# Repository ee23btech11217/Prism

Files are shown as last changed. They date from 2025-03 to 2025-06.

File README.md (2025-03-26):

# PrisM
Repository for PrisM, a custom FPGA-based handheld gaming console, built from scratch.

## Working with submodules
To work on this project, first clone the repo with submodules

```bash
    git clone --recurse-submodules --remote-submodules https://github.com/Y10-Labs/Prism
```

If you previously cloned this repo, without recurse submodules

```bash
    git fetch
    git pull
    git submodule update --init --recursive
```

If you are working on a submodule (Ex: Prism-SW), 

```bash
    cd Prism-SW
    git checkout main
```

And make changes.

When you are done making changes, 

```bash
    git add .
    git commit -m "Commit Message"
    git push
```

Then 
```bash
    cd ../ # Back to the project root
    git checkout main
    git submodule update 
    git add .
    git commit -m "Changed submodule X"
    git push
```

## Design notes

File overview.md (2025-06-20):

# PRISM: Custom Handheld Gaming Console

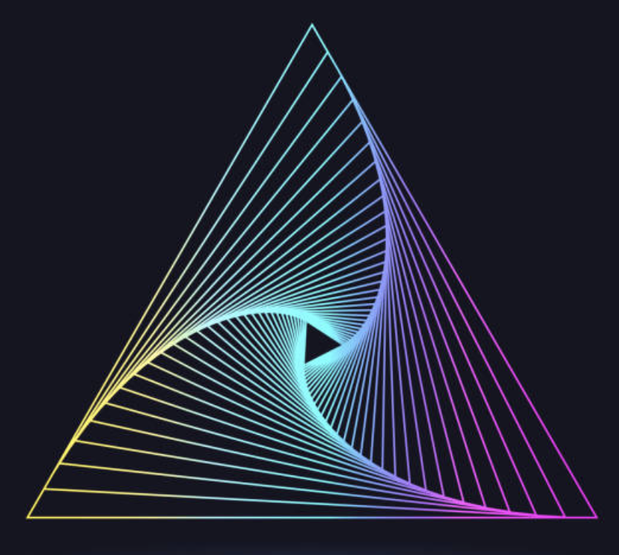
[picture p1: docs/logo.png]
Prism Logo


*A custom-built handheld gaming console with 3D-capable GPU and gyroscopic control*

## Overview

Prism is a handheld gaming console featuring a custom 3D-capable GPU implemented on a Zynq SoC FPGA, complete with fixed-function graphics pipeline and gyroscopic motion control. Designed by Y𝜄𝜋10𝜕 Labs as part of ESDP Lab at IIT Hyderabad.

## Technical Specifications

### Display
- **Resolution**: During development timeline, we plan on testing with the following resolutions
  - Mid-Spec: 400 × 240 @ 60fps
  - Low-Spec: 200 × 120 @ 30fps
- **Screen Size**: 5-inch LCD Panel @ 60Hz
- **Pixel Density**: 151 PPI
- **Color Support**: 15-bit RGB (32,768 colors)

### Controls
- **Gyroscopic Motion**: 6-axis IMU sensor (LSM6DSL)
- **Analog Joystick**: Full 360° with variable pressure
- **D-Pad**: 4-button pad

### Hardware Architecture
- **SoC**: Xilinx Zynq-7000 Series
- **Memory**: 256 MB DDR3 SDRAM
- **Storage**: 2 x SD Card / ROM
- **Graphics**: Custom GPU pipeline implemented in FPGA and ARM core
  - Vertex Shader
  - Shape Assembly
  - Rasterization
  - Pixel Shader
- **Custom Audio Engine**: 
  - Capable of handling upto 255 Channels, each with primitive DSP effects, to interface with the game.
  - Supports basic 2D Spatial Audio

## PCB Design

Mentioning [juliancoy](https://github.com/juliancoy/zynqPCB) as his open-source Zynq PCB design helped us a lot as a starting point.

We heavily modified the design, to incorporate out requirements, and the PCB design looks as follows.

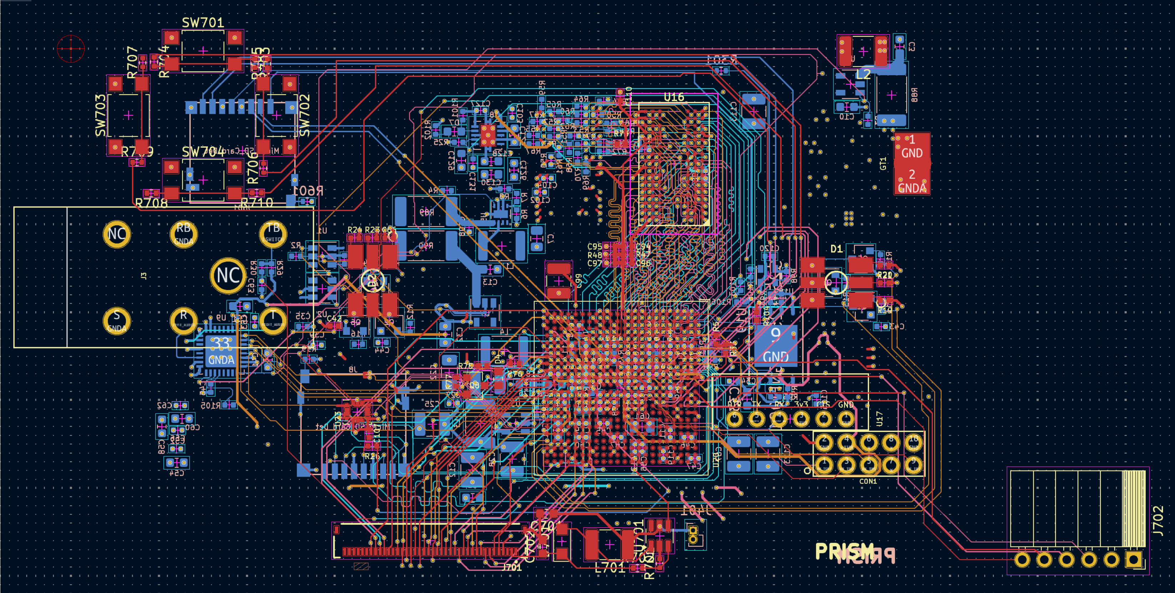
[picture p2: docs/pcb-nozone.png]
pcbnozone

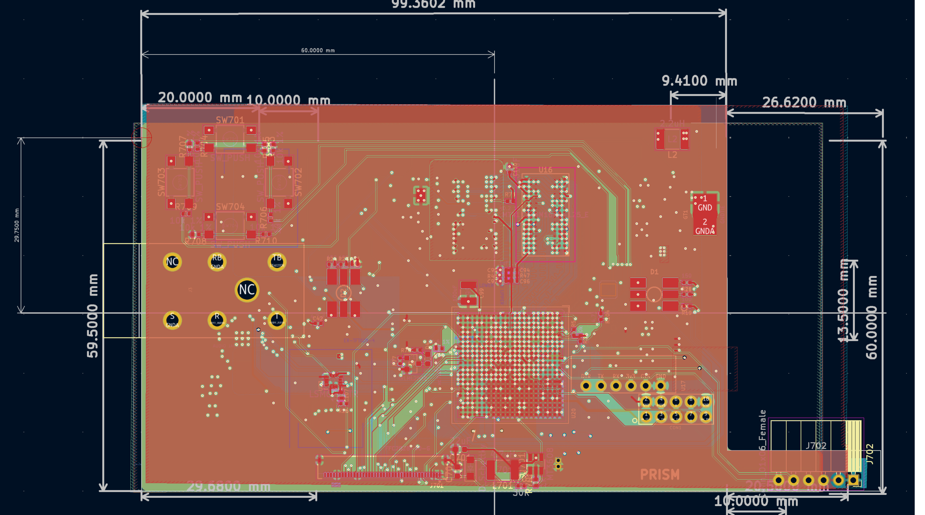
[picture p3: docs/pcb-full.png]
pcbzone

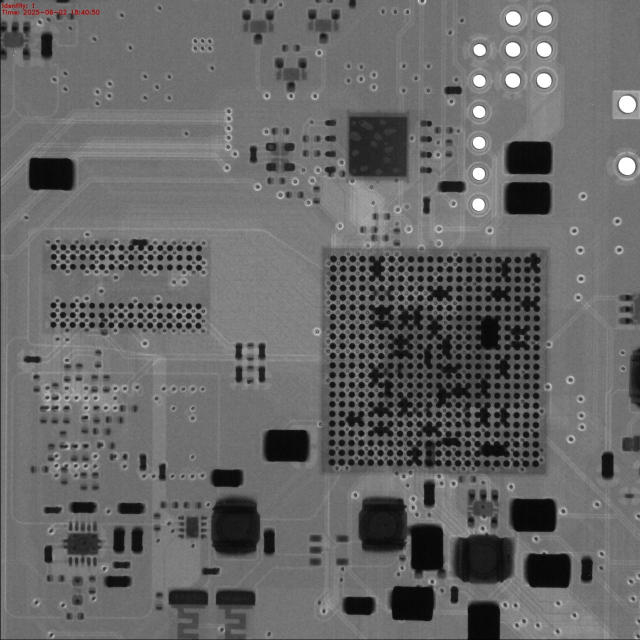
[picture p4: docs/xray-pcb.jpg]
pcbxray

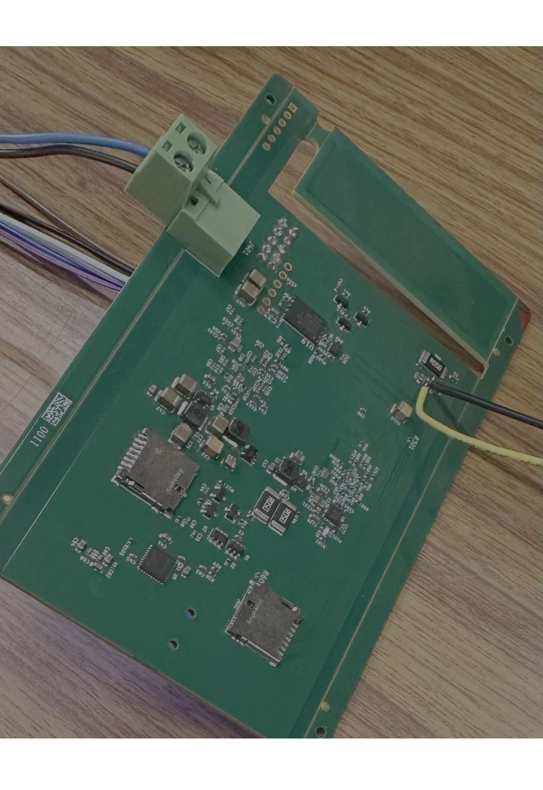
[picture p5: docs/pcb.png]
pcb


## Enclosure

We 3D printed the outer case for the console. The design has space to draw cables out to remaining parts. (It was spray-painted red)
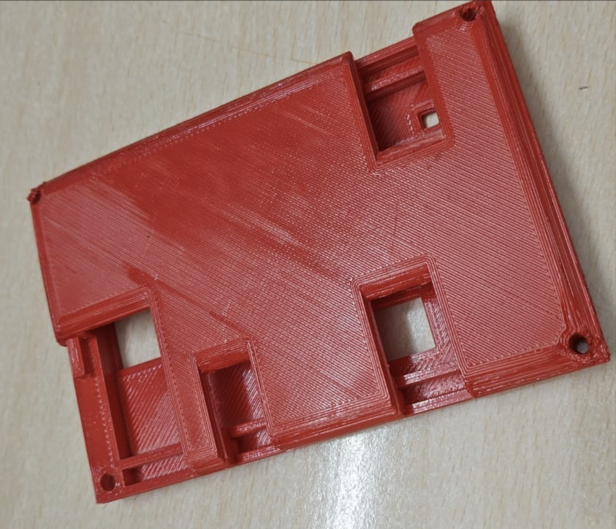
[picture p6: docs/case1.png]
case1

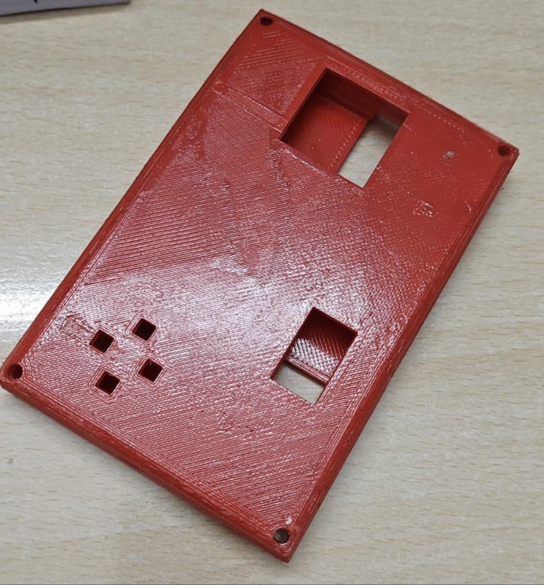
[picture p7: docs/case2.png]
case2


## Software Architecture

### Programming Interface
- C++ for game development (Runs on Petalinux OS)

### Libraries
- **Driver Layer**: Hardware abstraction for:
  - Display output
  - Control inputs
  - Sensors
- **Graphics Layer**:
  - 3D model loading (Loads OBJ only for now)
  - Scene graph management
  - Camera controls

### Game Development Tools
  - Optional OpenGL linking to test game on computer. 

## Project Structure

- **Hardware Design**: PCB and schematic files for Zynq FPGA-based board
- **FPGA Development**: Verilog sources for processor core and GPU
- **Drivers**: C++ access layers for hardware components
- **Graphics Library**: GL-compatible rendering system
- **Emulation**: OpenGL-based desktop emulator

**Software is still under progress**

## Development Timeline

The project is supposed to follow the following timeline:
1. **Phase 1**: Architecture design and specifications freeze
2. **Phase 2**: Low-spec implementation (200 × 120 @ 60fps)
3. **Phase 3**: Mid-spec implementation (400 × 240 @ 60fps)
4. **Phase 4**: PCB design/fabrication and hardware assembly
5. **Phase 5**: Game development and testing

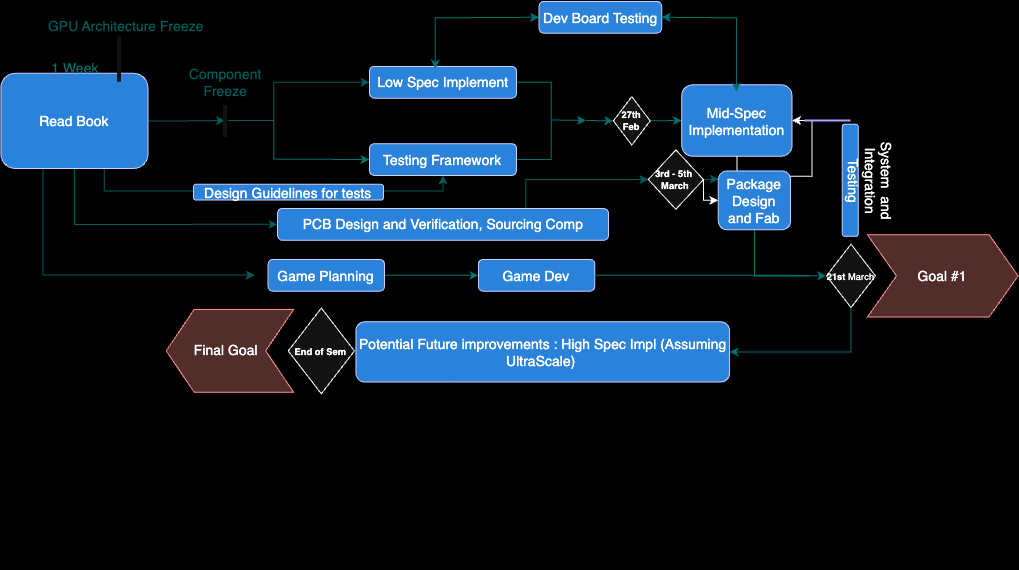
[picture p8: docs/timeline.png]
tiemline


Of course, as with any project, the timeline was only a mere suggestion for what was to happen. We technically hit goals for finishing the PCB, and then waited after that to do everything else.

## Team

Y𝜄𝜋10𝜕 Labs:
- Adarsh A (EE23BTECH11203)
- Manohar K (EE23BTECH11208)
- Prajwal M (EE23BTECH11217)
- Mihir Divyansh Eachempati (EE23BTECH11017)
- Soham Prabhakar More (EE23BTECH11223)
- Sri Krishna Prabhas Yadla (EE23BTECH11224)

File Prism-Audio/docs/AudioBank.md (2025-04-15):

# The PrismAudioBank Format

## Overview

The PrismAudio Bank (.pab) format is a binary container designed to store multiple audio files (wave) for real-time playback on embedded systems. It uses a hierarchical categorization system (Category → Subcategory → Index) to organize sounds

## File Structure

A PrismAudio Bank file consists of three main sections:

1. **Main Header** (20 bytes) - Contains file metadata
2. **Entry Headers** (22 bytes each) - Contains metadata for each audio file
3. **Audio Data** - Contains the raw audio sample data

### Main Header (20 bytes)

| Offset | Size | Type | Description |
|---|---|---|---|
| 0 | 9 | char[9]  | Magic identifier ("PRSMAUBNK") |
| 9 | 1 | uint8_t  | Format version |
| 10 | 4 | uint32_t | Number of entries |
| 14 | 4 | uint32_t | Total header size (22 + 20×entries) |
| 18 | 4 | uint32_t | Total file size |

### Entry Header (22 bytes)

Each entry header contains metadata for one audio sample:

| Offset | Size | Type | Description |
|---|---|---|---|
| 0 | 1 | uint8_t  | Category ID |
| 1 | 1 | uint8_t  | Subcategory ID |
| 2 | 2 | uint16_t | Sound index |
| 4 | 4 | uint32_t | Offset to audio data from start of file |
| 8 | 4 | uint32_t | Length of audio data in bytes |
| 12 | 4 | uint32_t | Number of frames (samples) |
| 16 | 4 | uint32_t | Sample rate in Hz |

### Audio Data Blocks

The audio data section contains raw audio data for each entry:

- Each block contains raw PCM audio data (16-bit samples)
- Blocks are 4-byte aligned
- Block sizes match the lengths specified in the corresponding entry headers
- Blocks appear in the same order as their entry headers

## Sound Identification

Sounds are identified by a three-part hierarchical ID:

- **Category** (uint8_t): Primary classification (e.g., 1=Ambient, 2=Character)
- **Subcategory** (uint8_t): Secondary classification (e.g., 1=Background, 2=Weather)
- **Index** (uint16_t): Specific sound within the subcategory

These three values can be combined to form a unique identifier for each sound in the bank.
```verilog
    32'b{{cat},{subcat},{idx}}
```

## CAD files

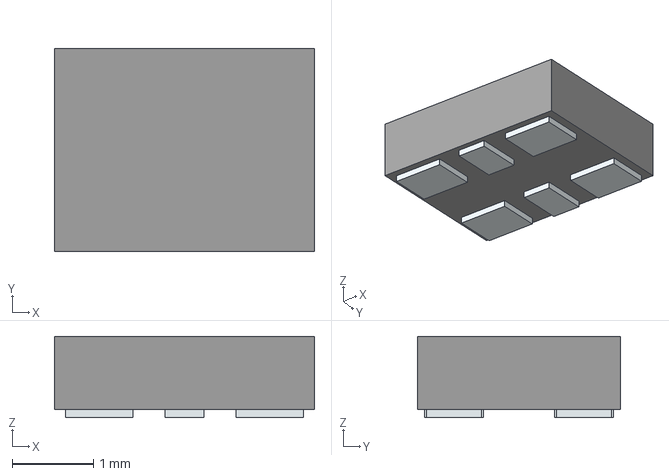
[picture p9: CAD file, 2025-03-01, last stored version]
PCB/custom/LIB_DSC1121CE5-050.0000/DSC1121CE5-050.0000/3D/DSC1121CE5-050.0000.stp
3.20 x 2.50 x 1.00 mm
Pins

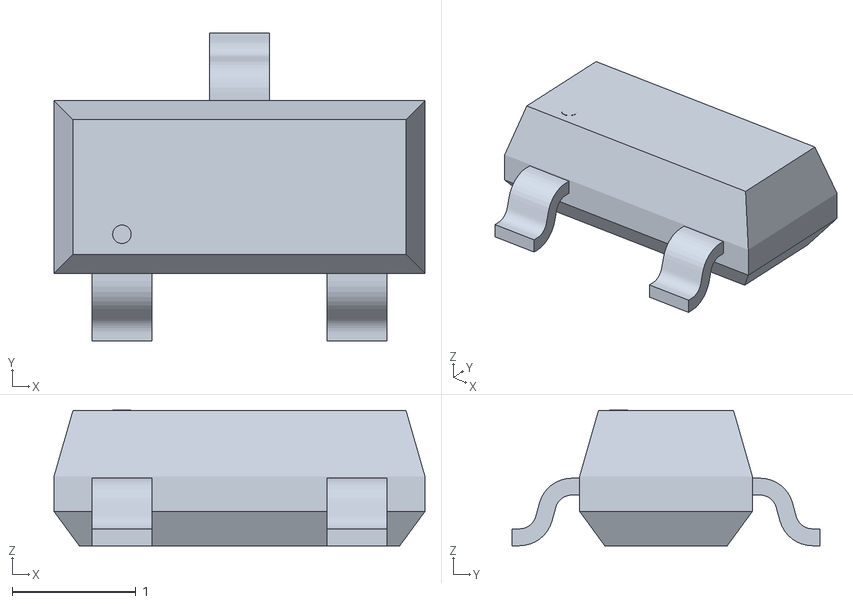
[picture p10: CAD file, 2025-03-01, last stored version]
PCB/custom/PMBT3904_215/SOT23_TO-236AB_NEX.stl
3.00 x 2.49 x 1.10

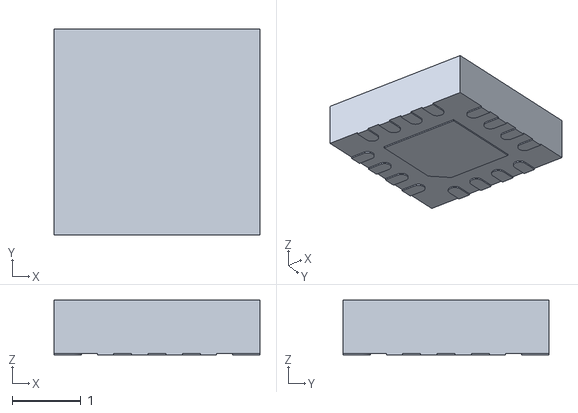
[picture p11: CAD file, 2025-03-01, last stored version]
PCB/custom/TPA6132A2RTET/RTE0016B.stl
3.00 x 3.00 x 0.8

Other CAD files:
PCB/custom/LIB_DSC1121CE5-050.0000/DSC1121CE5-050.0000/Allegro/dsc1121ce50500000.psm
PCB/custom/LIB_DSC1121CE5-050.0000/DSC1121CE5-050.0000/DEHDL/dsc1121ce5_050.0000/chips/chips.prt

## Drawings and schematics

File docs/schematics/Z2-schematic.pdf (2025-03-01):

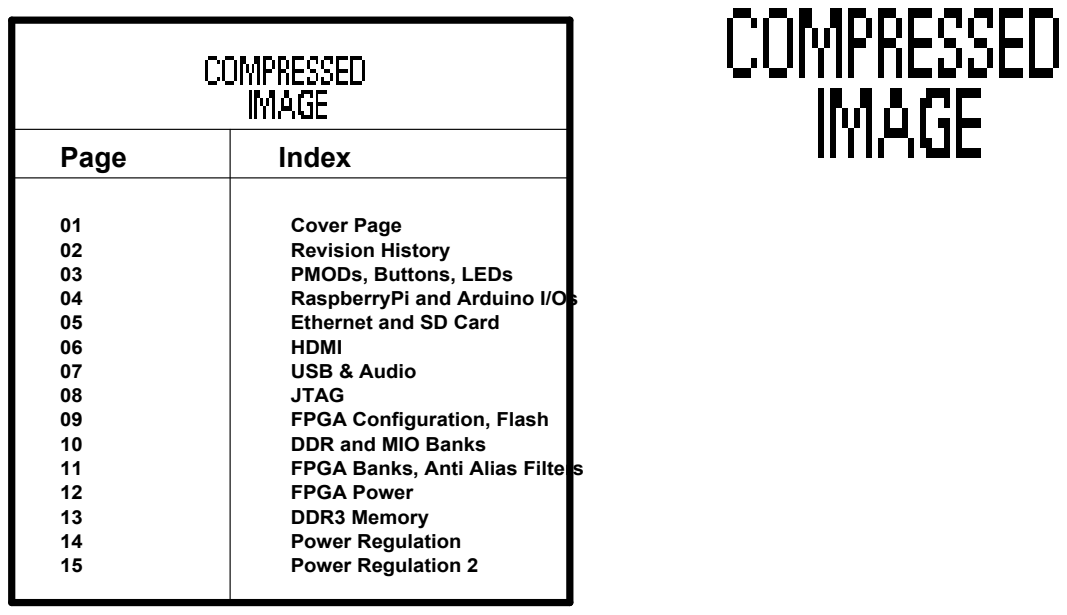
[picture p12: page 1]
Tul Corporation; TEL: +886 2 8698 3000; FAX: +886 2 8698 3456; Cover Page

Page | Index

01 02 Revision History 03 04 05 06 07 08 09 10 11 FPGA Banks, Anti Alias Filters 12 FPGA Power 13 DDR3 Memory 14 Power Regulation 15 Power Regulation 2 | Cover Page PMODs, Buttons, LEDs RaspberryPi and Arduino I/Os Ethernet and SD Card HDMI USB & Audio JTAG FPGA Configuration, Flash DDR and MIO Banks

7F-7,NO.79, HSIN TAI WU RD. SEC 1,
HSI-CHIH, TAIPEI HSIEN, TAIWAN 221
Title

Size A3 | Document Number PYNQ-Z2 | Rev R10

Date: Tuesday, January 09, 2018 Tuesday, January 09, 2018 Tuesday, January 09, 2018 | Sheet 1 1 1 of 15 15 15

# REV

# REVISION HISTORY:

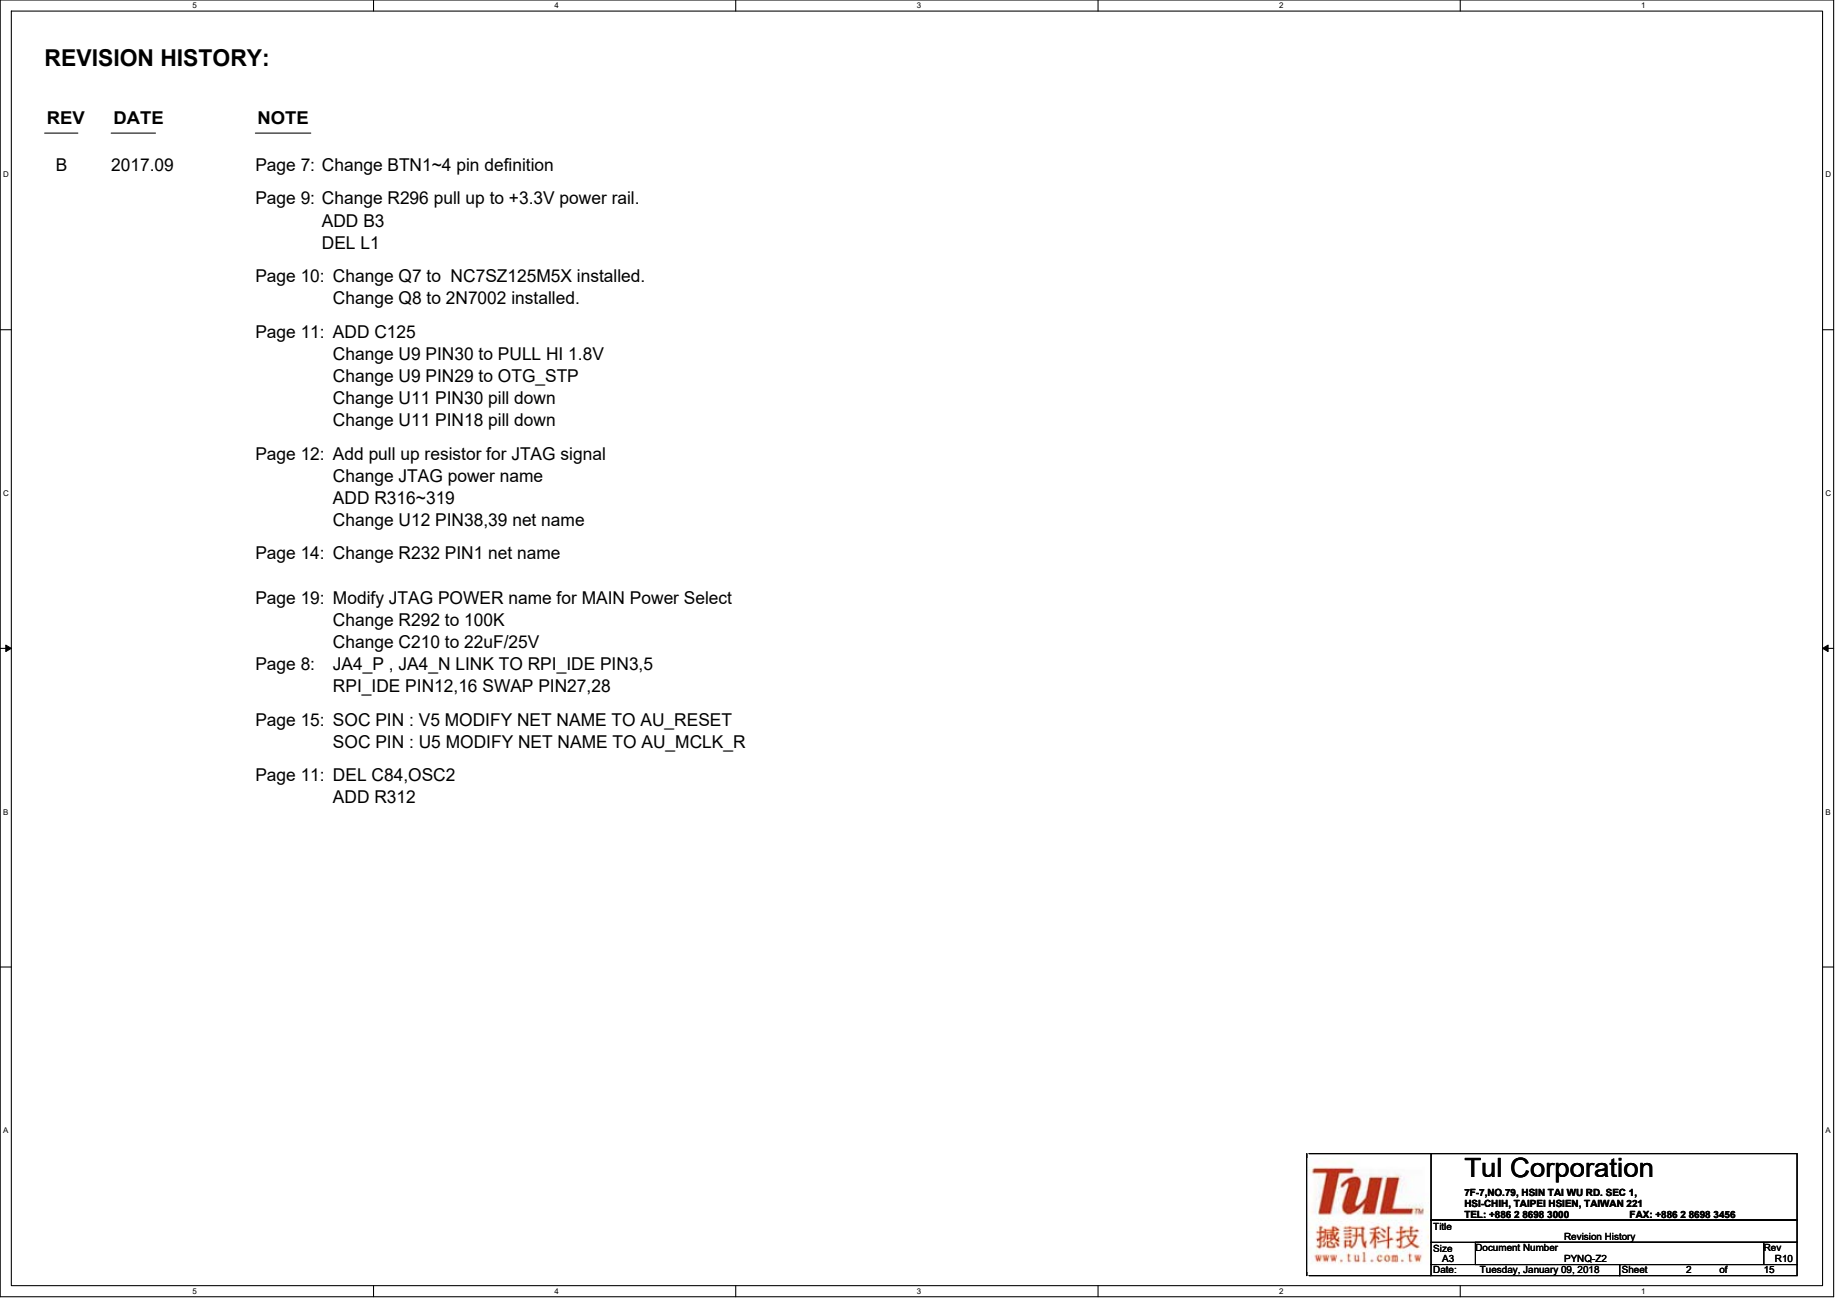
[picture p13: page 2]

Page 9: Change R296 pull up to +3.3V power rail.

Page 10: Change Q7 to NC7SZ125M5X installed.

Change U9 PIN30 to PULL HI 1.8V
Change U9 PIN29 to OTG_STP
Change U11 PIN30 pill down
Change U11 PIN18 pill down

Page 12: Add pull up resistor for JTAG signal

Change JTAG power name
ADD R316~319
Change U12 PIN38,39 net name

Page 14: Change R232 PIN1 net name

Page 19: Modify JTAG POWER name for MAIN Power Select

Page 15: SOC PIN : V5 MODIFY NET NAME TO AU_RESET

SOC PIN : U5 MODIFY NET NAME TO AU_MCLK_R

7F-7,NO.79, HSIN TAI WU RD. SEC 1,

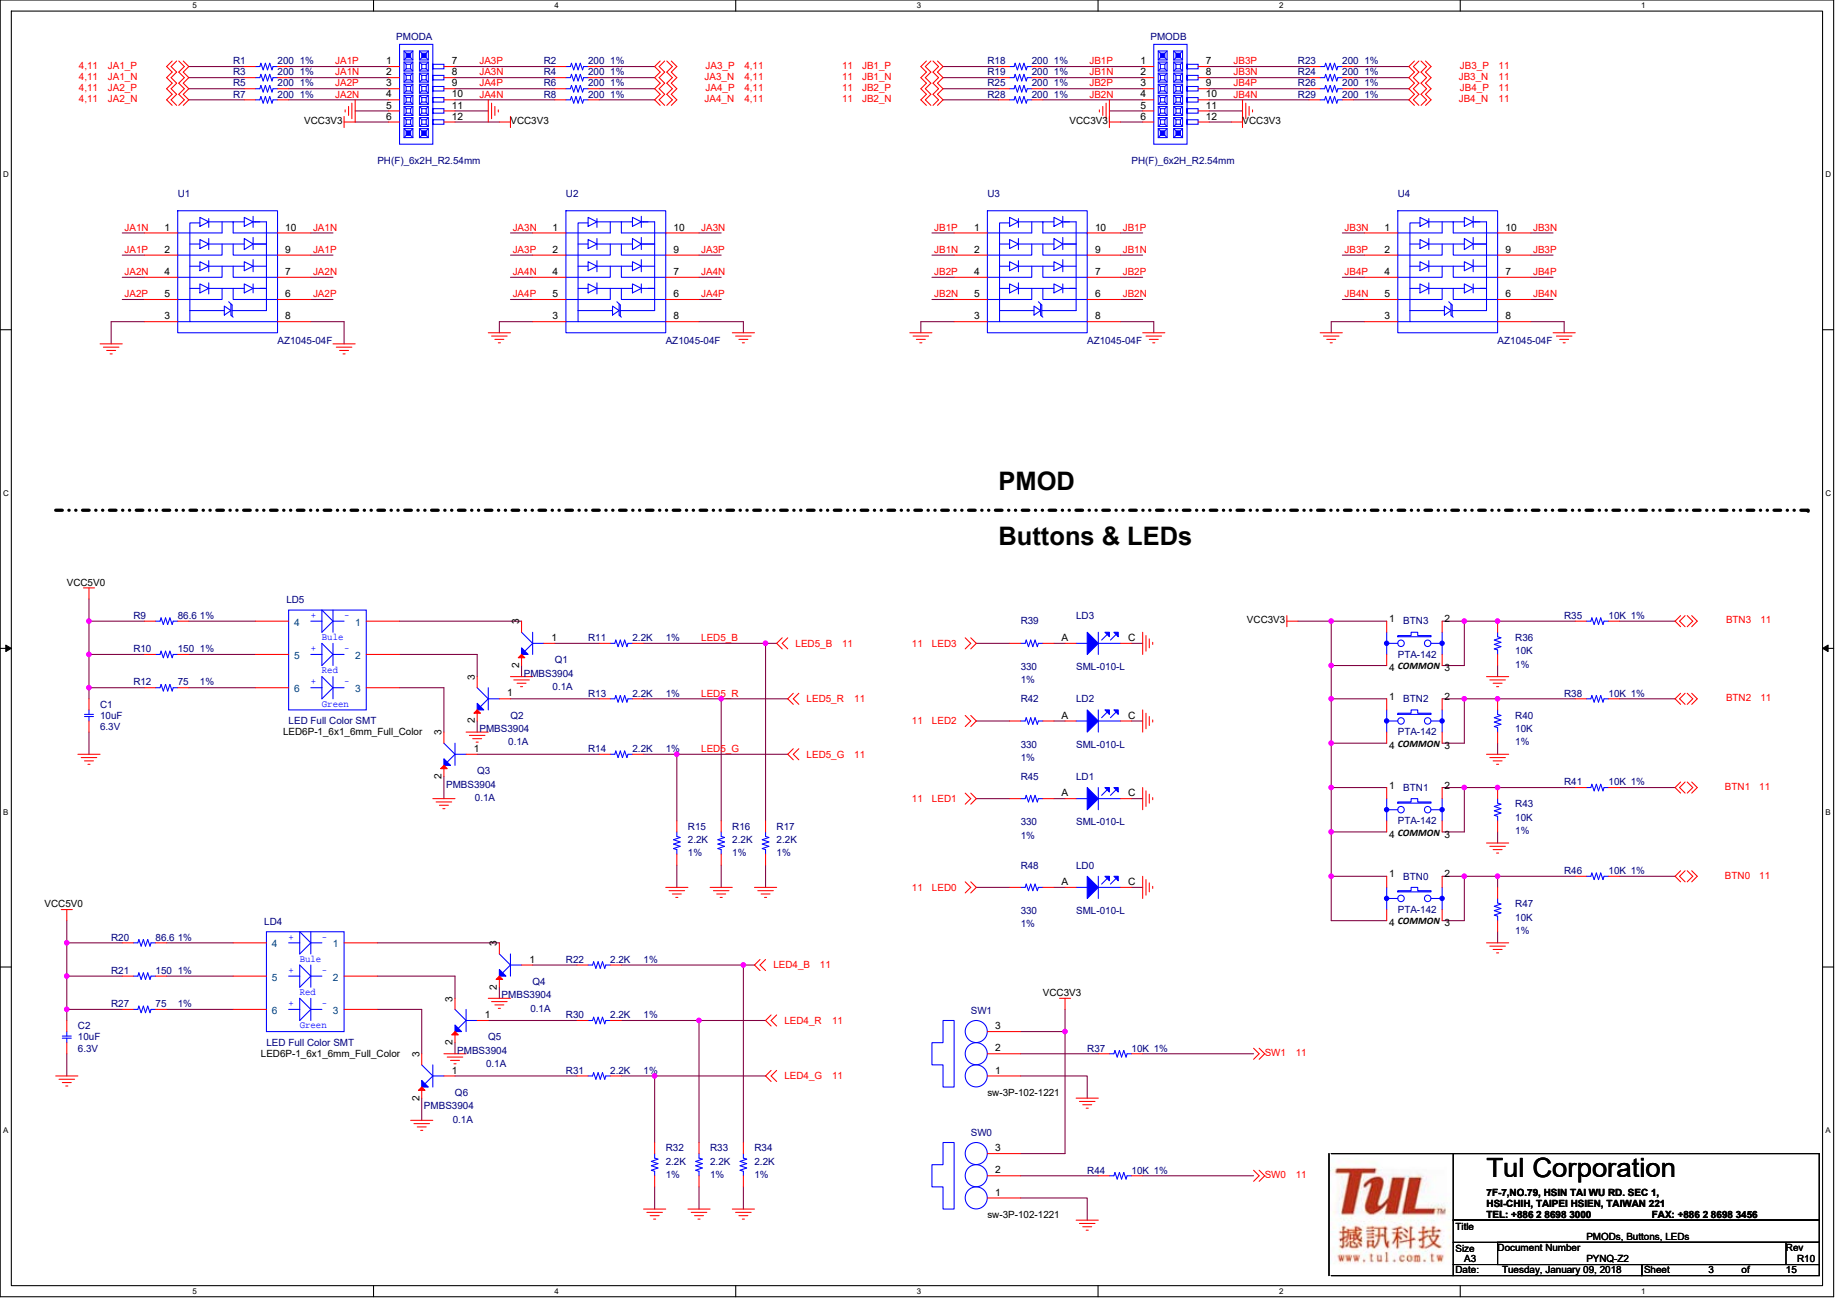
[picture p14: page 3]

LED Full Color SMT
LED6P-1_6x1_6mm_Full_Color

7F-7,NO.79, HSIN TAI WU RD. SEC 1,

Arduino I/Os | Raspberry Pi

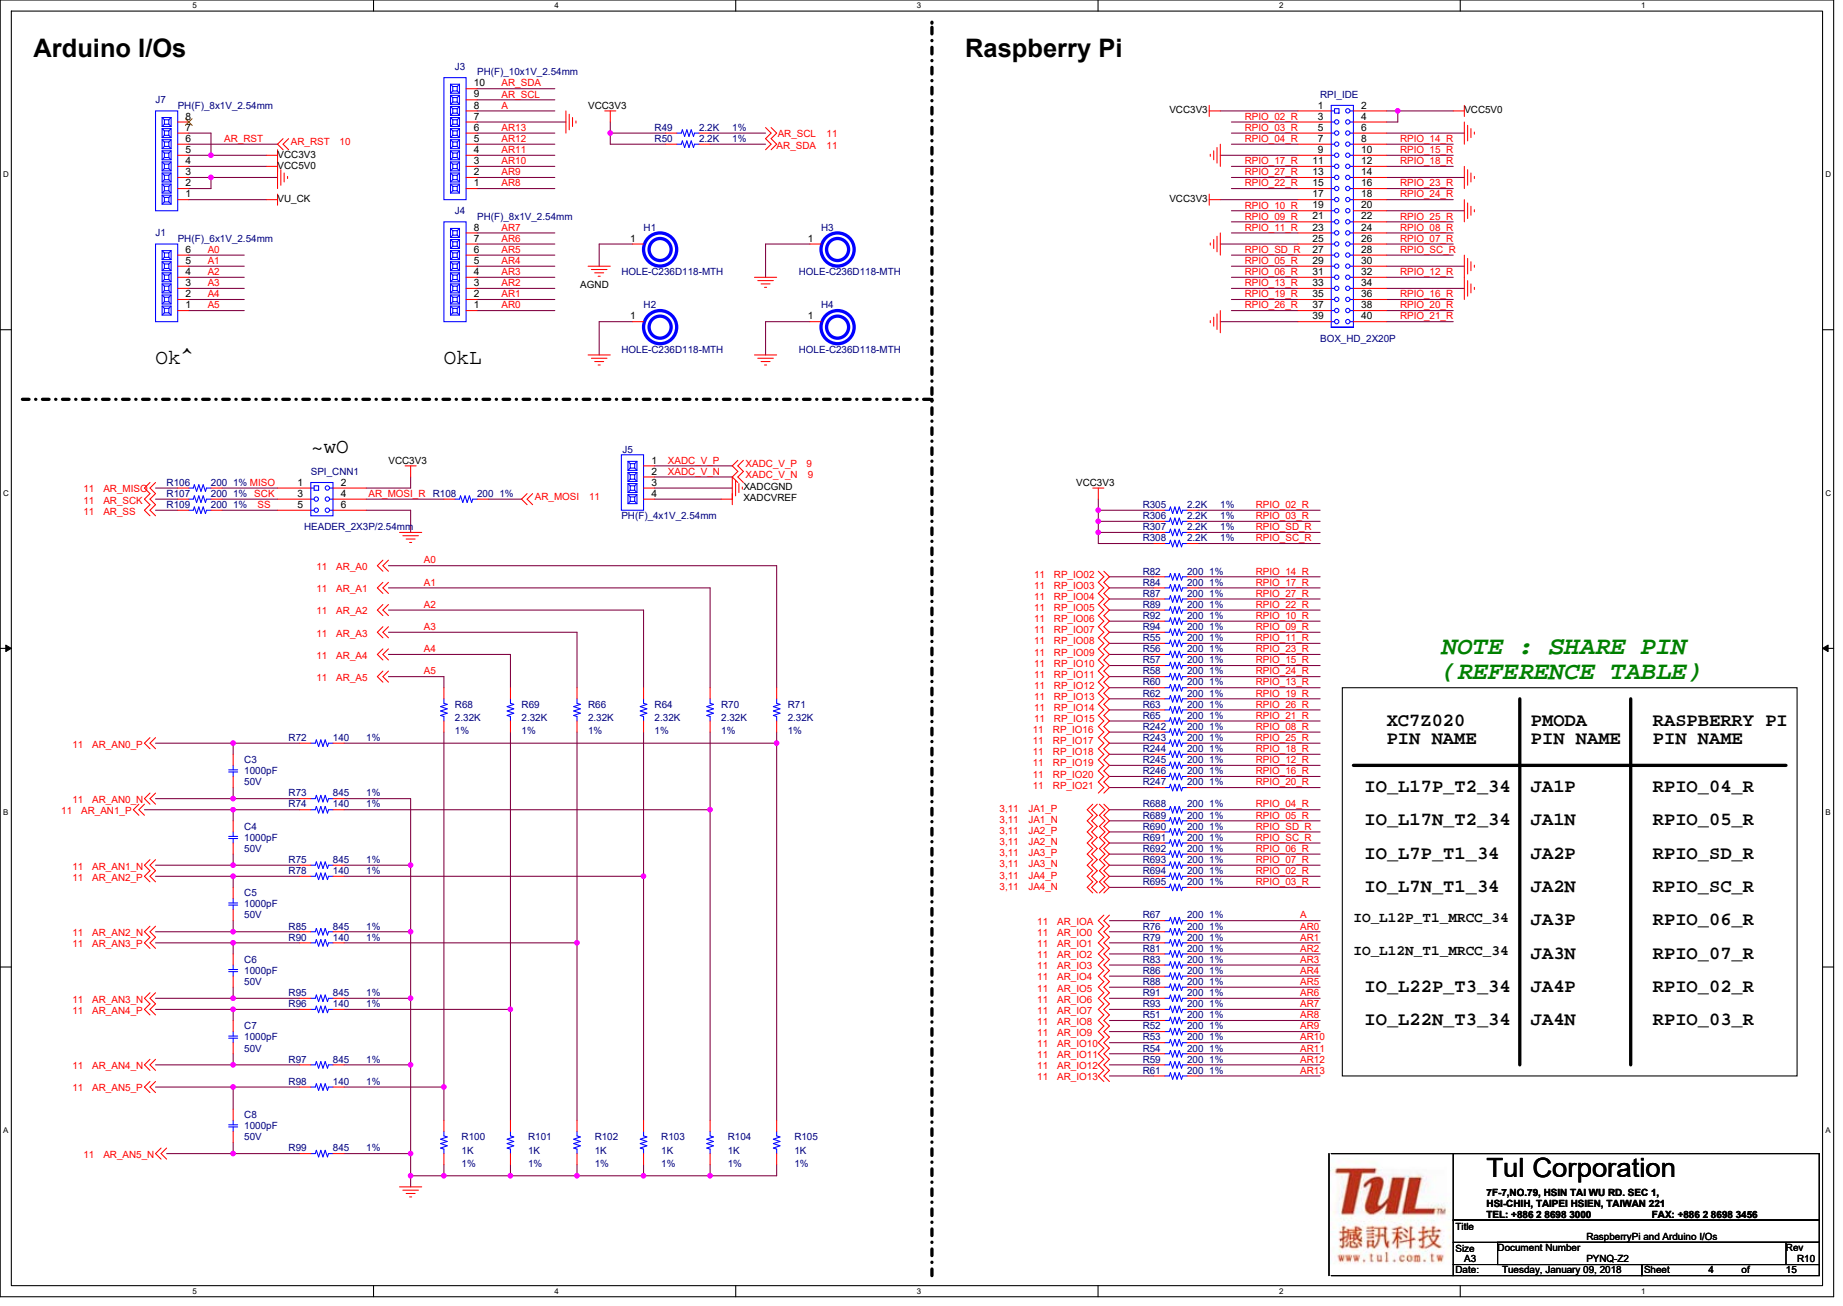
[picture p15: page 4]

7F-7,NO.79, HSIN TAI WU RD. SEC 1,

RaspberryPi and Arduino I/Os

# Ethernet

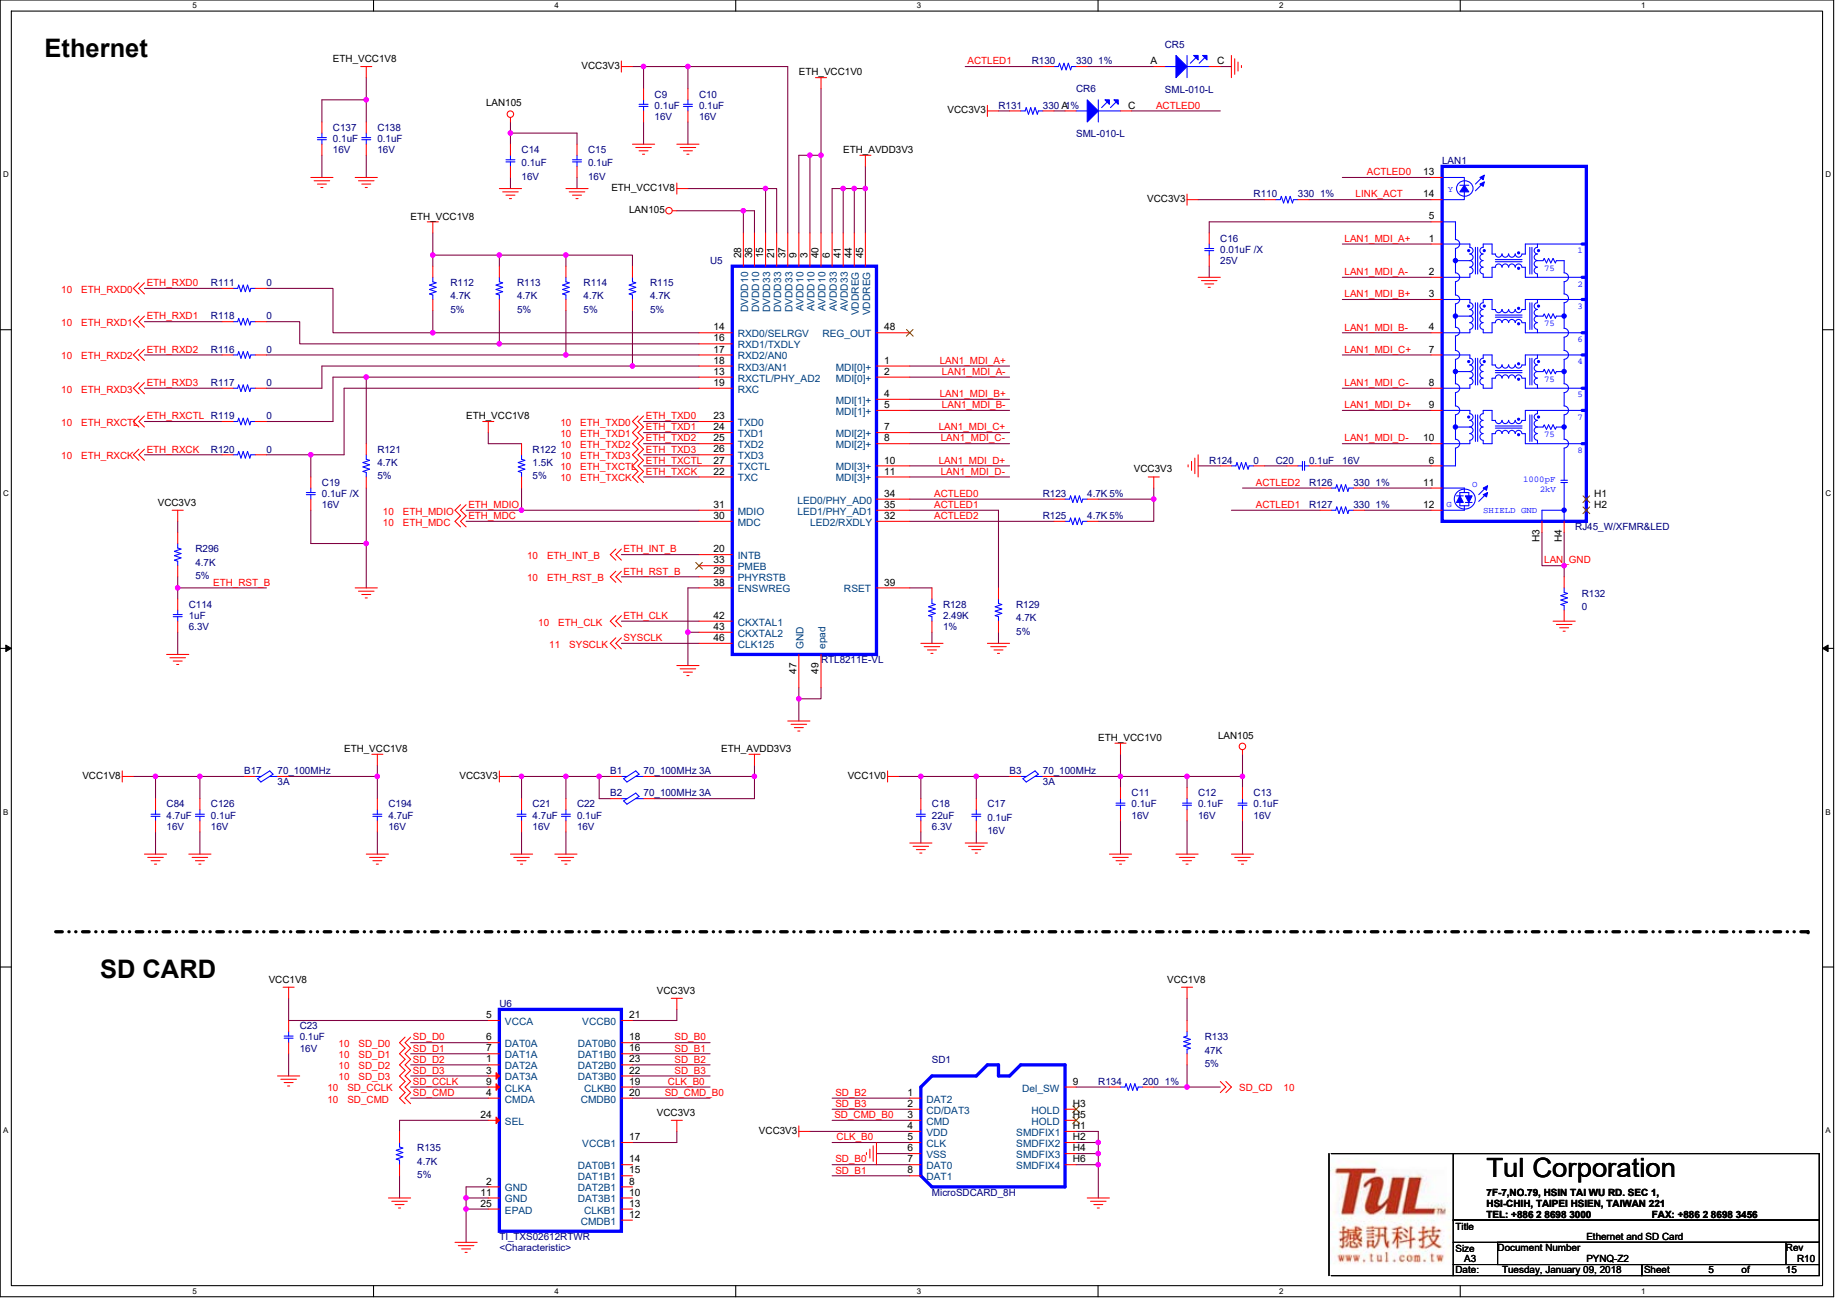
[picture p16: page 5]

7F-7,NO.79, HSIN TAI WU RD. SEC 1,

Ethernet and SD Card

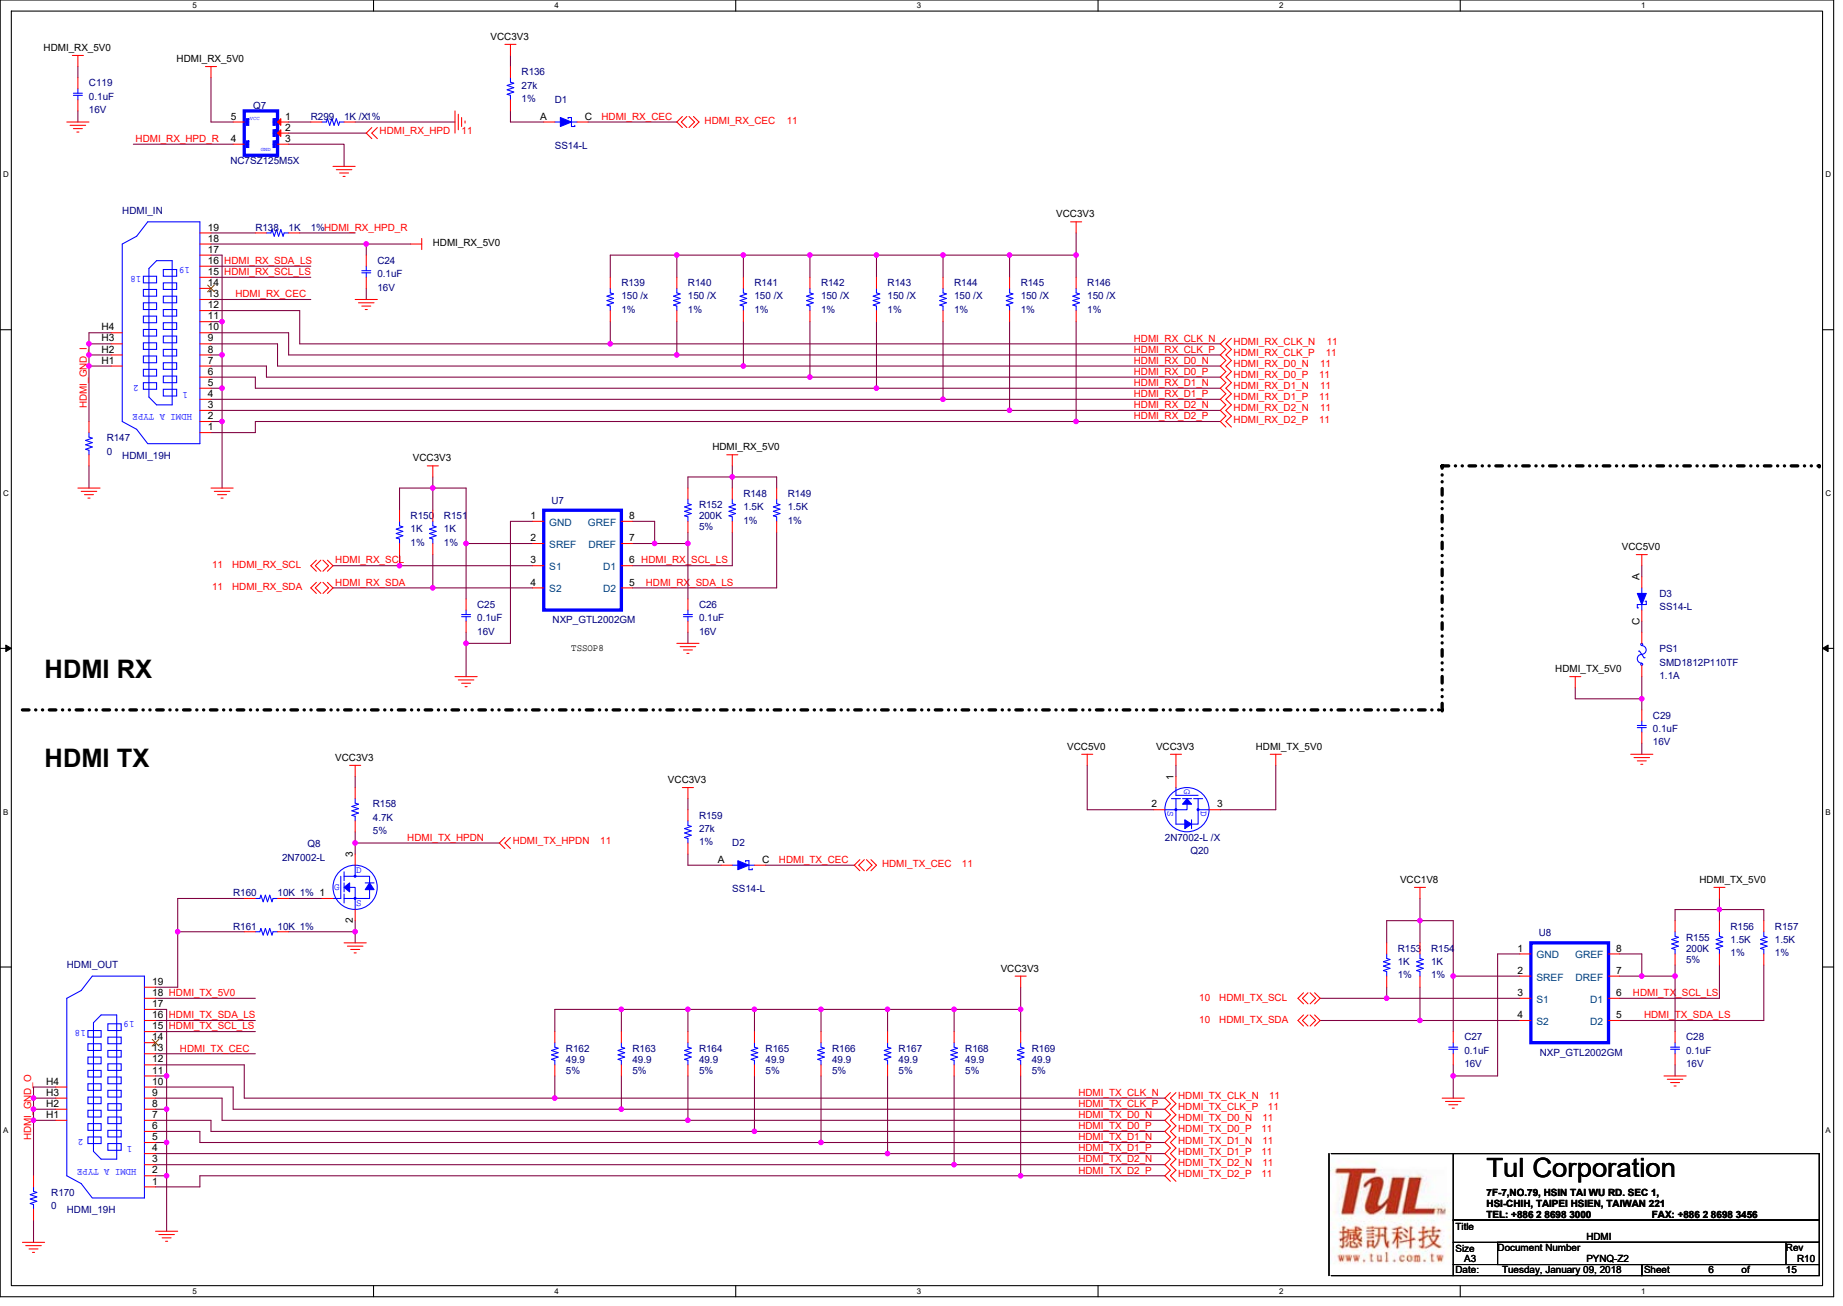
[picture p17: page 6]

7F-7,NO.79, HSIN TAI WU RD. SEC 1,

# USB

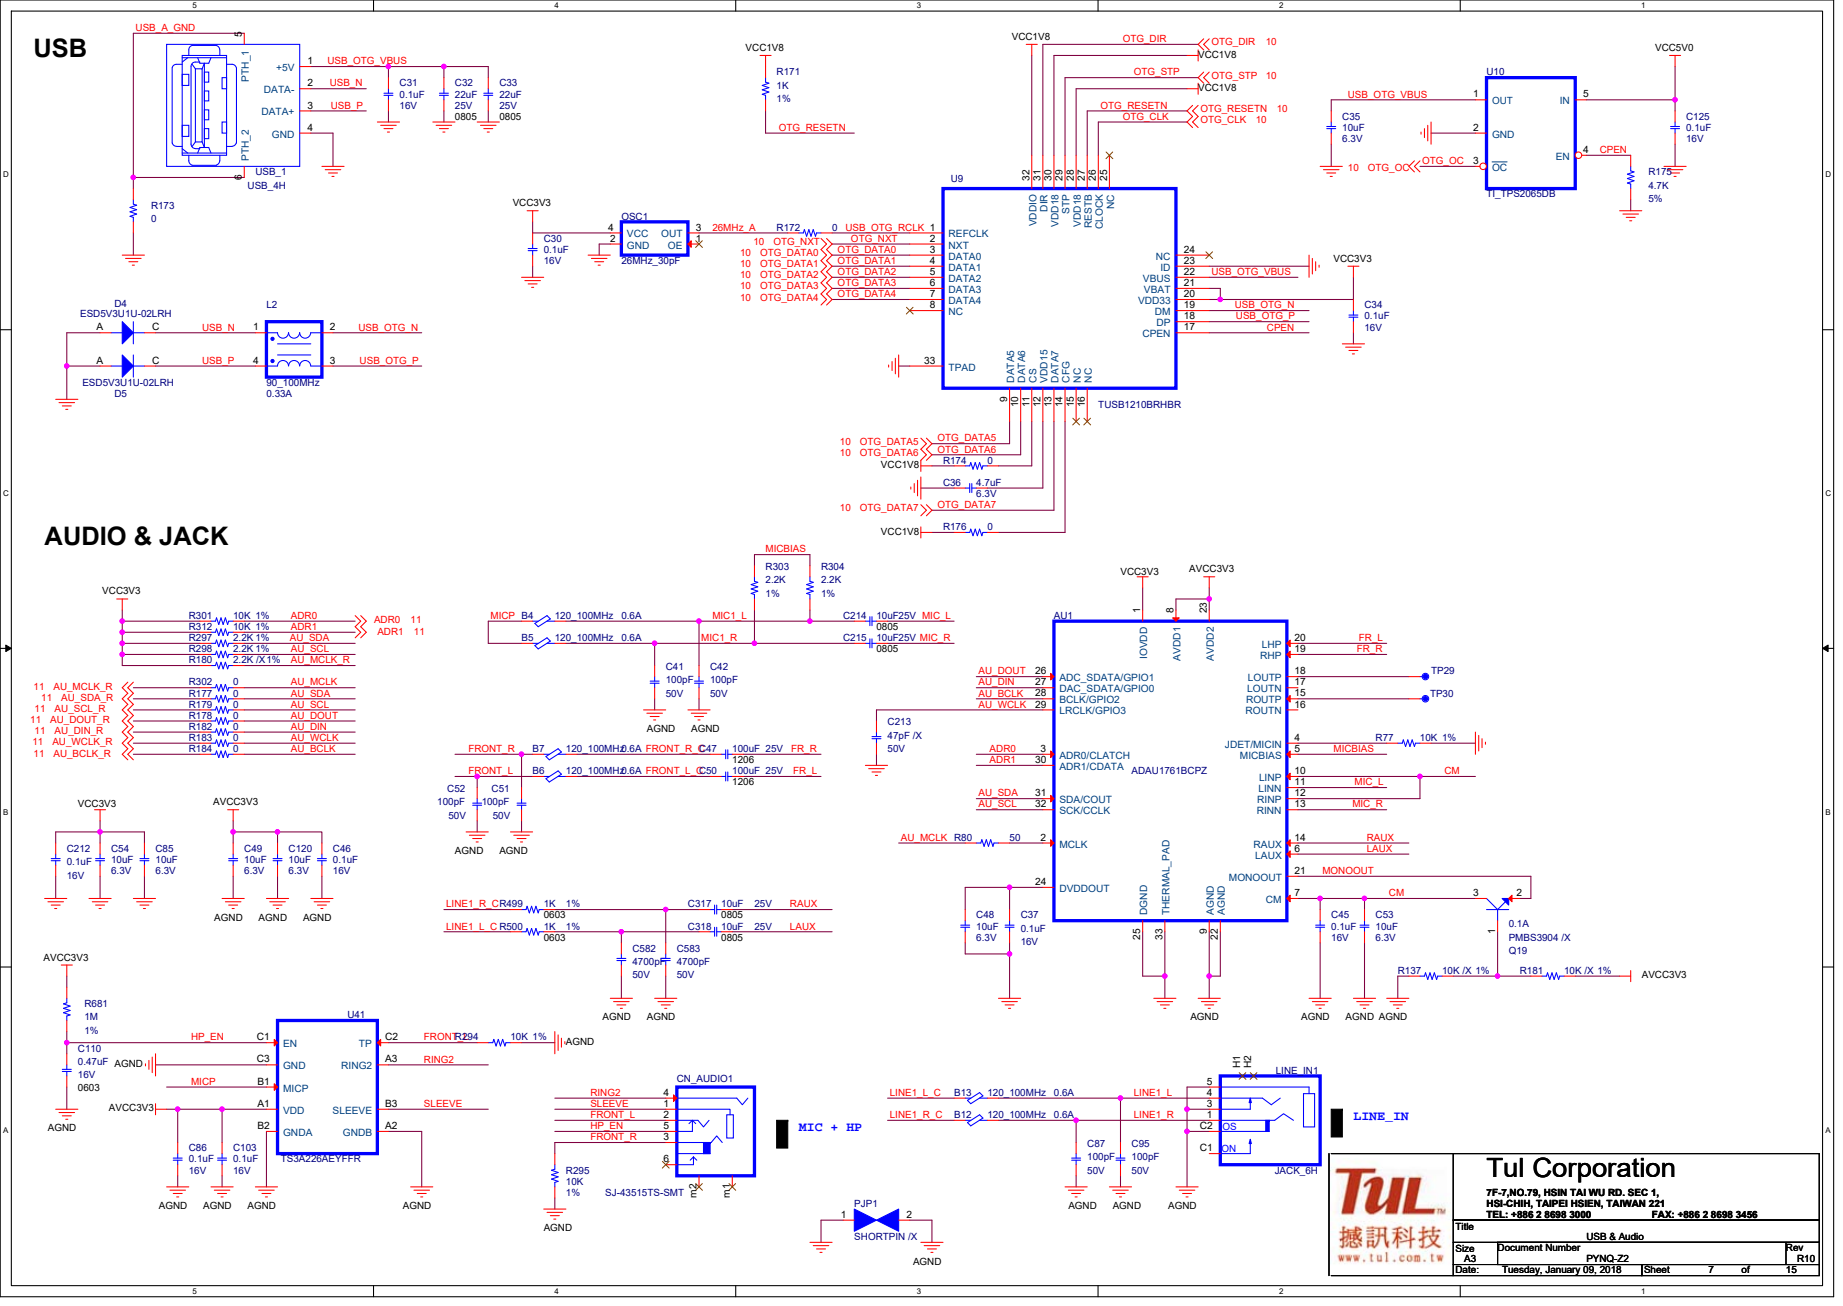
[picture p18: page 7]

NC 25 CLOCK 26 RESTB 27 VDD18 28 STP 29 VDD18 30 DIR 31 VDDIO 32

7F-7,NO.79, HSIN TAI WU RD. SEC 1,

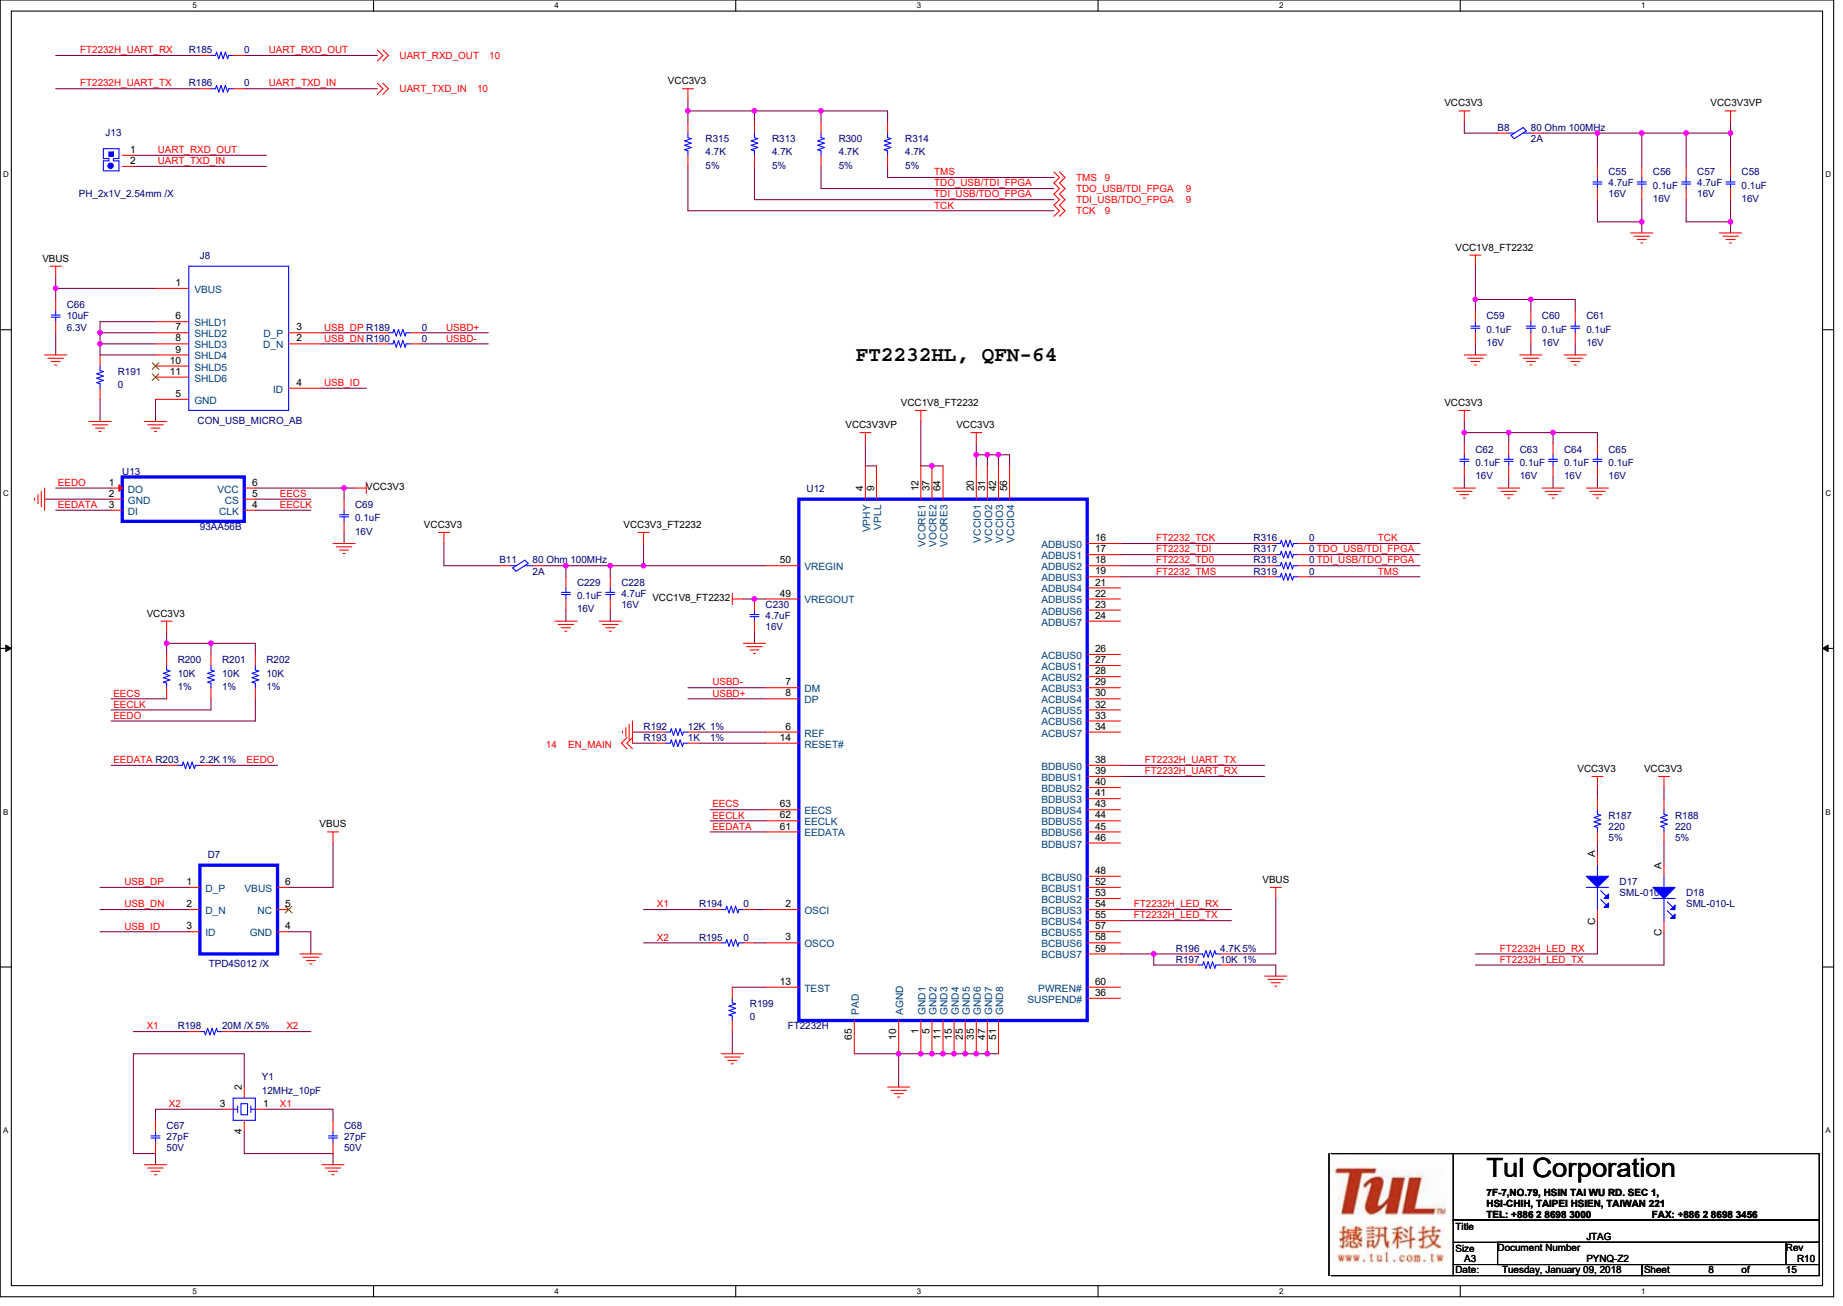
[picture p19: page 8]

7F-7,NO.79, HSIN TAI WU RD. SEC 1,

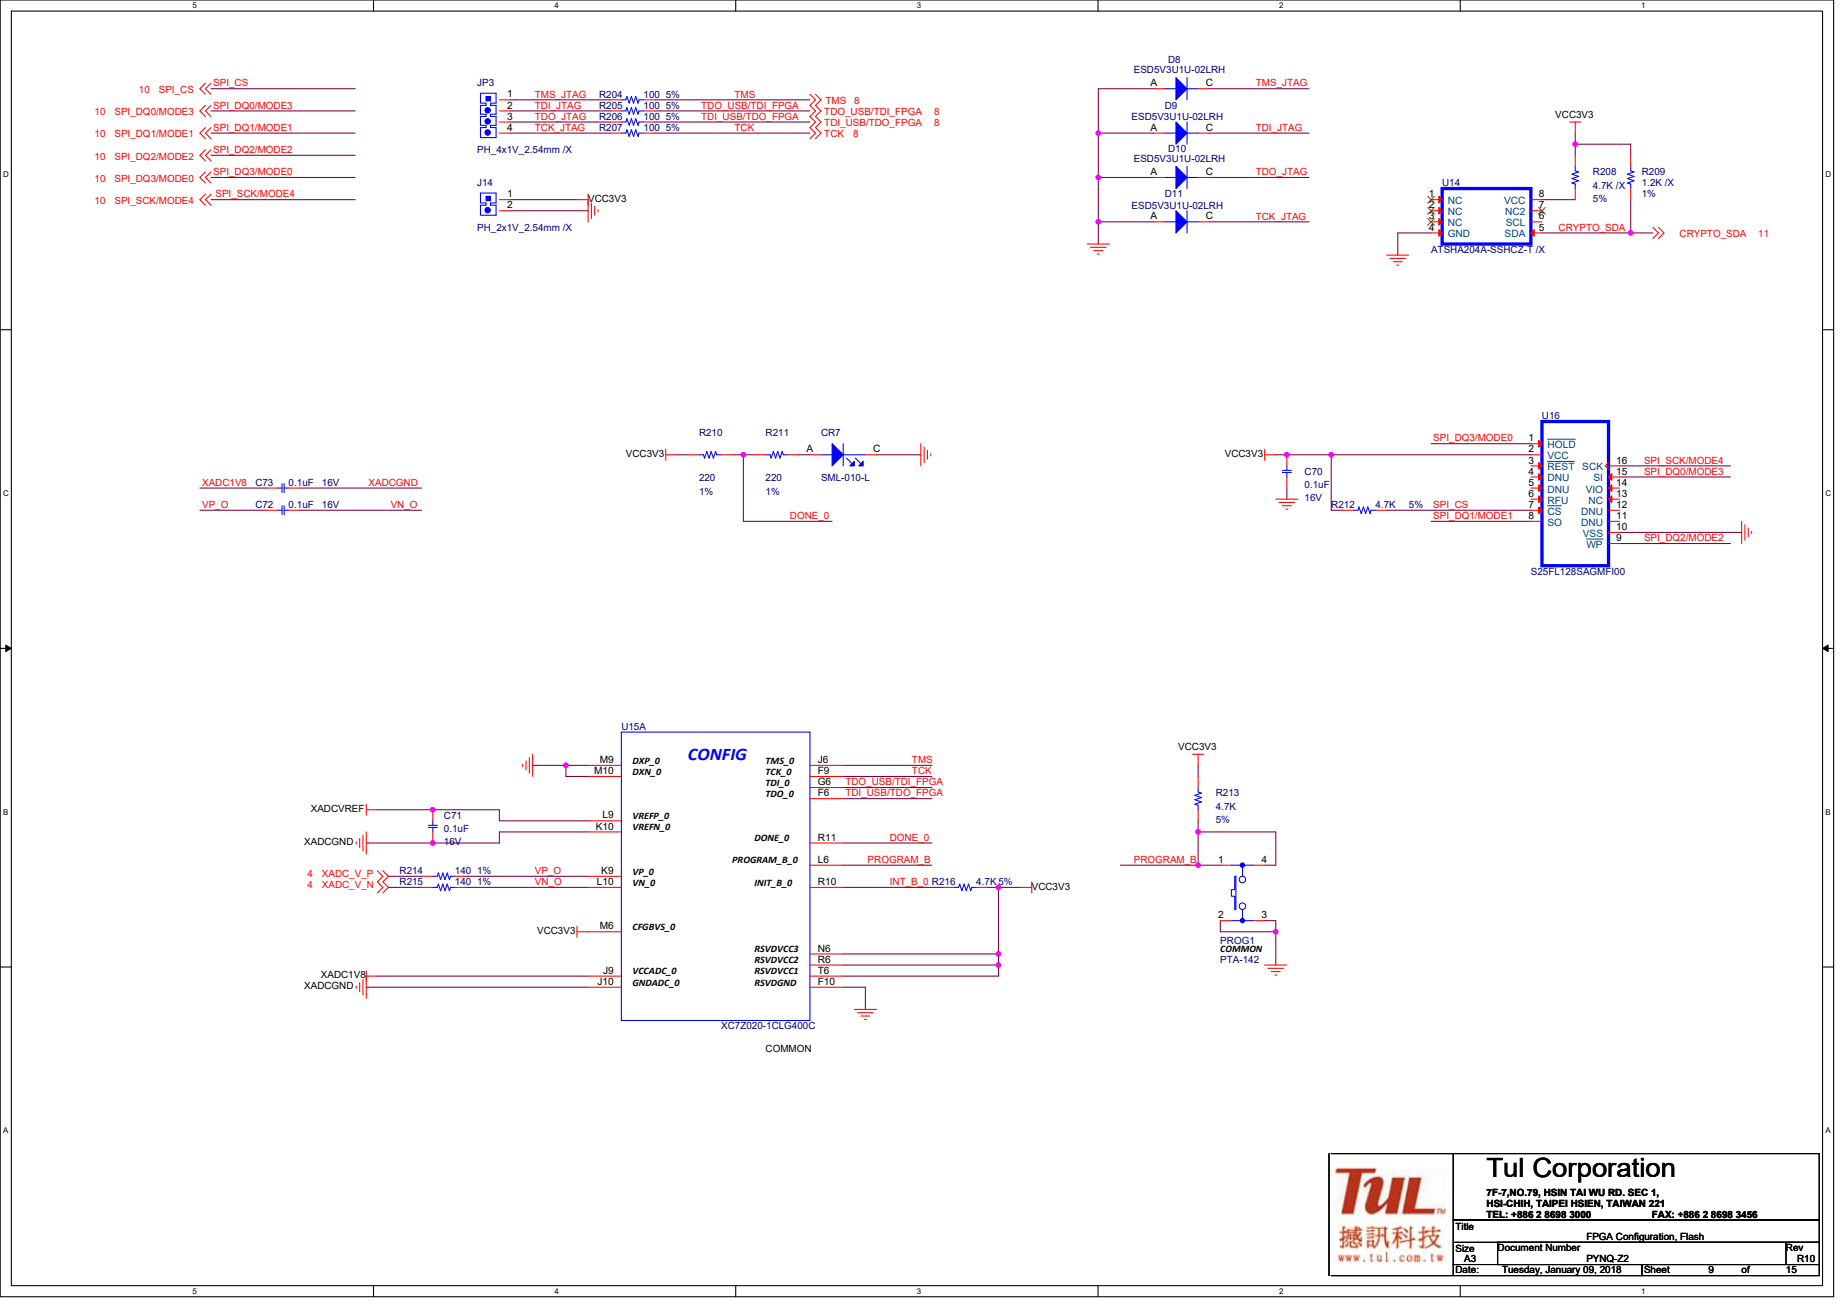
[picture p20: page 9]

7F-7,NO.79, HSIN TAI WU RD. SEC 1,

## Bank 501

## DDR PORT 502

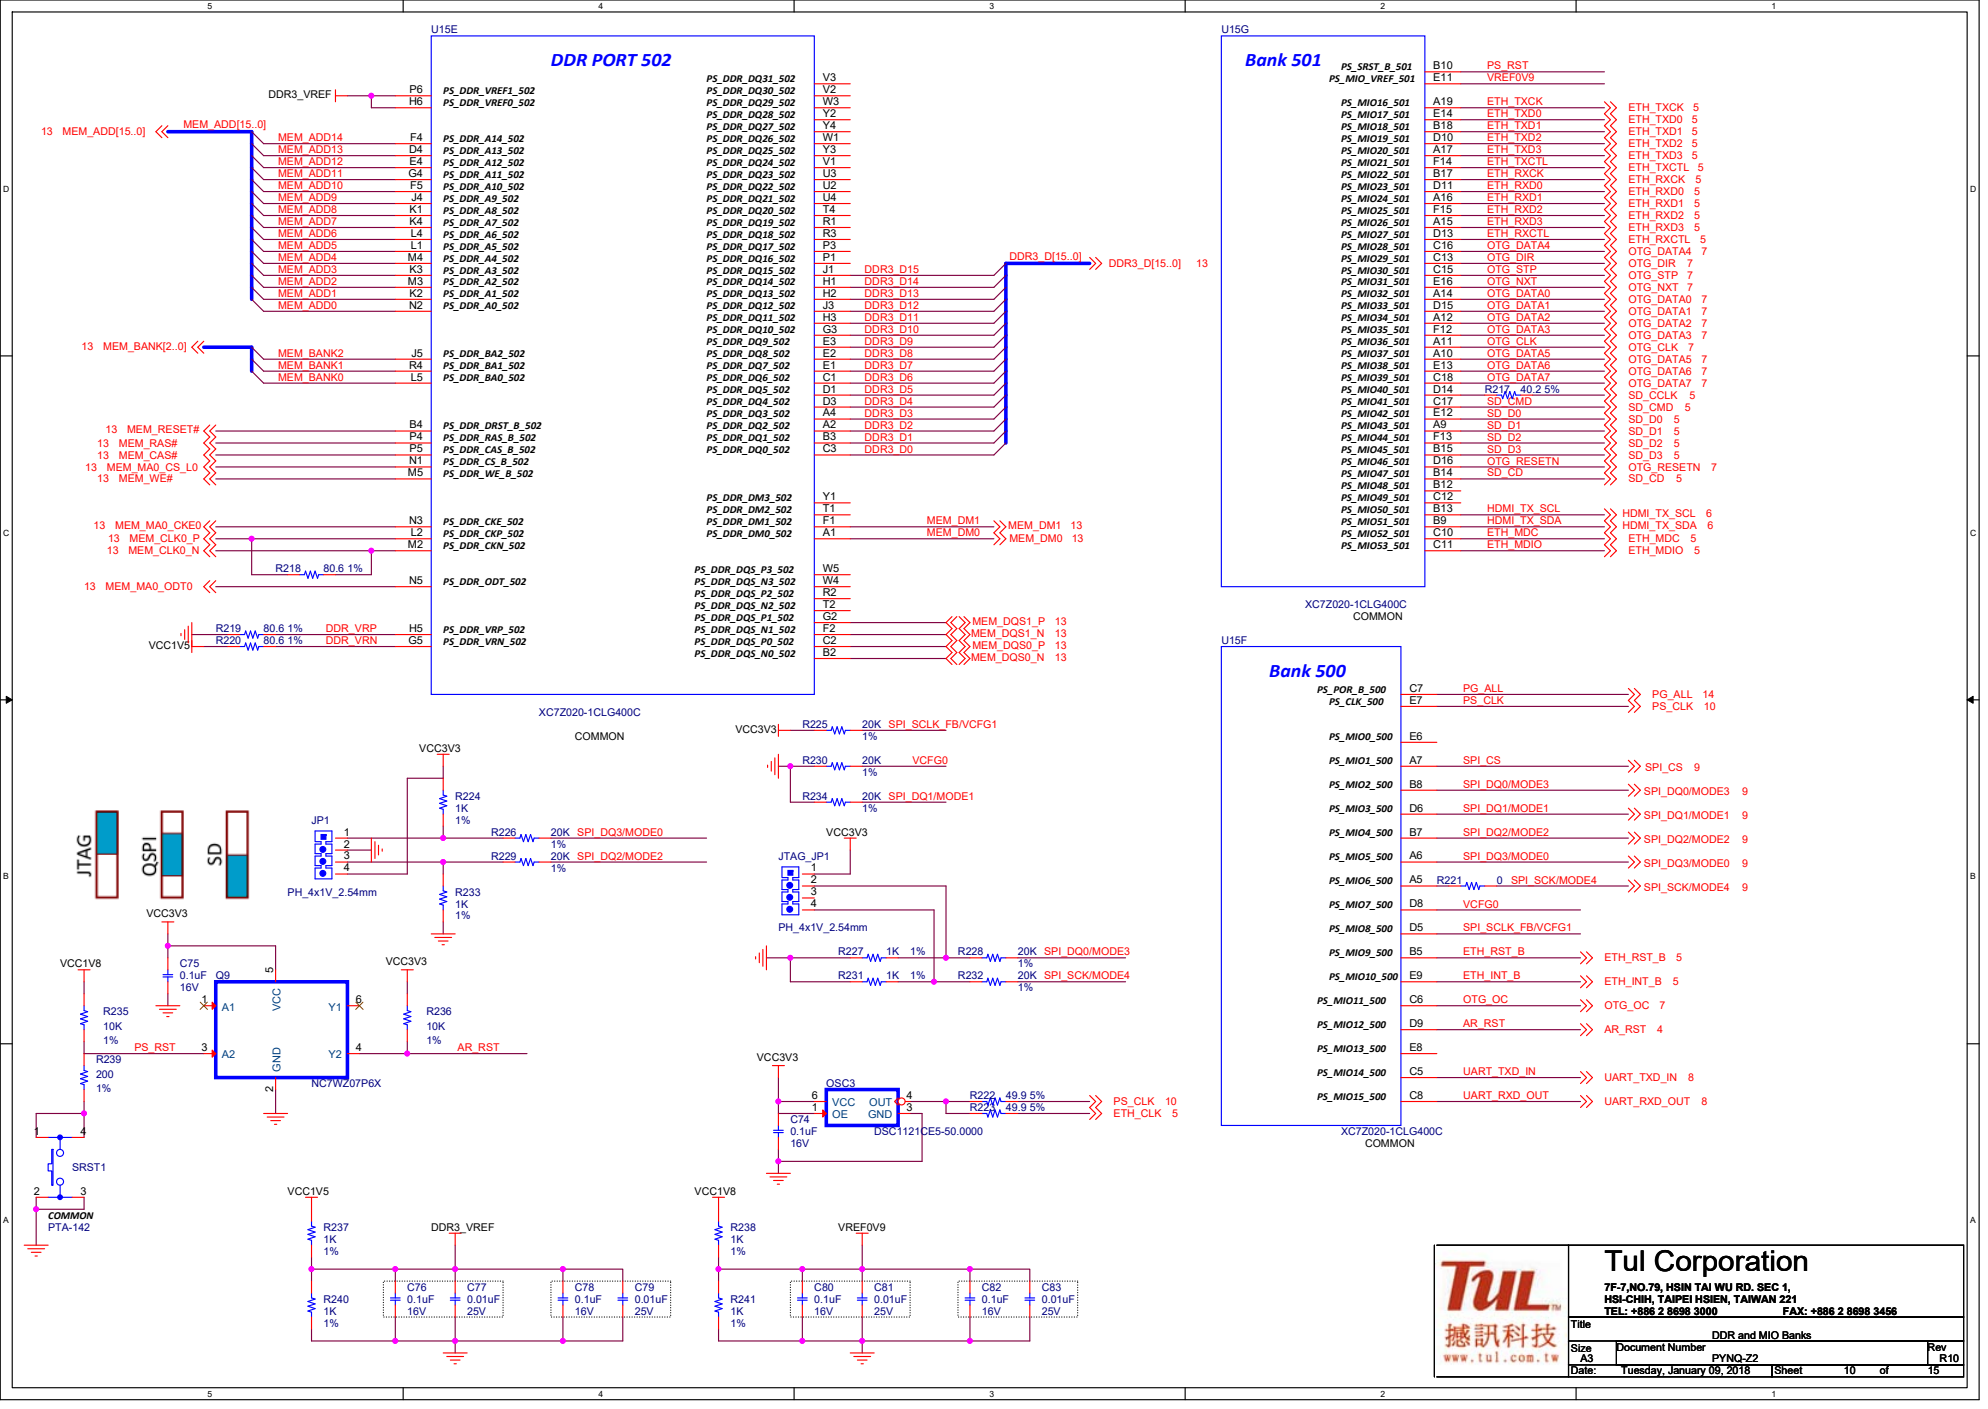
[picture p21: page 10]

7F-7,NO.79, HSIN TAI WU RD. SEC 1,

DDR and MIO Banks

## BANK 13

## BANK 34

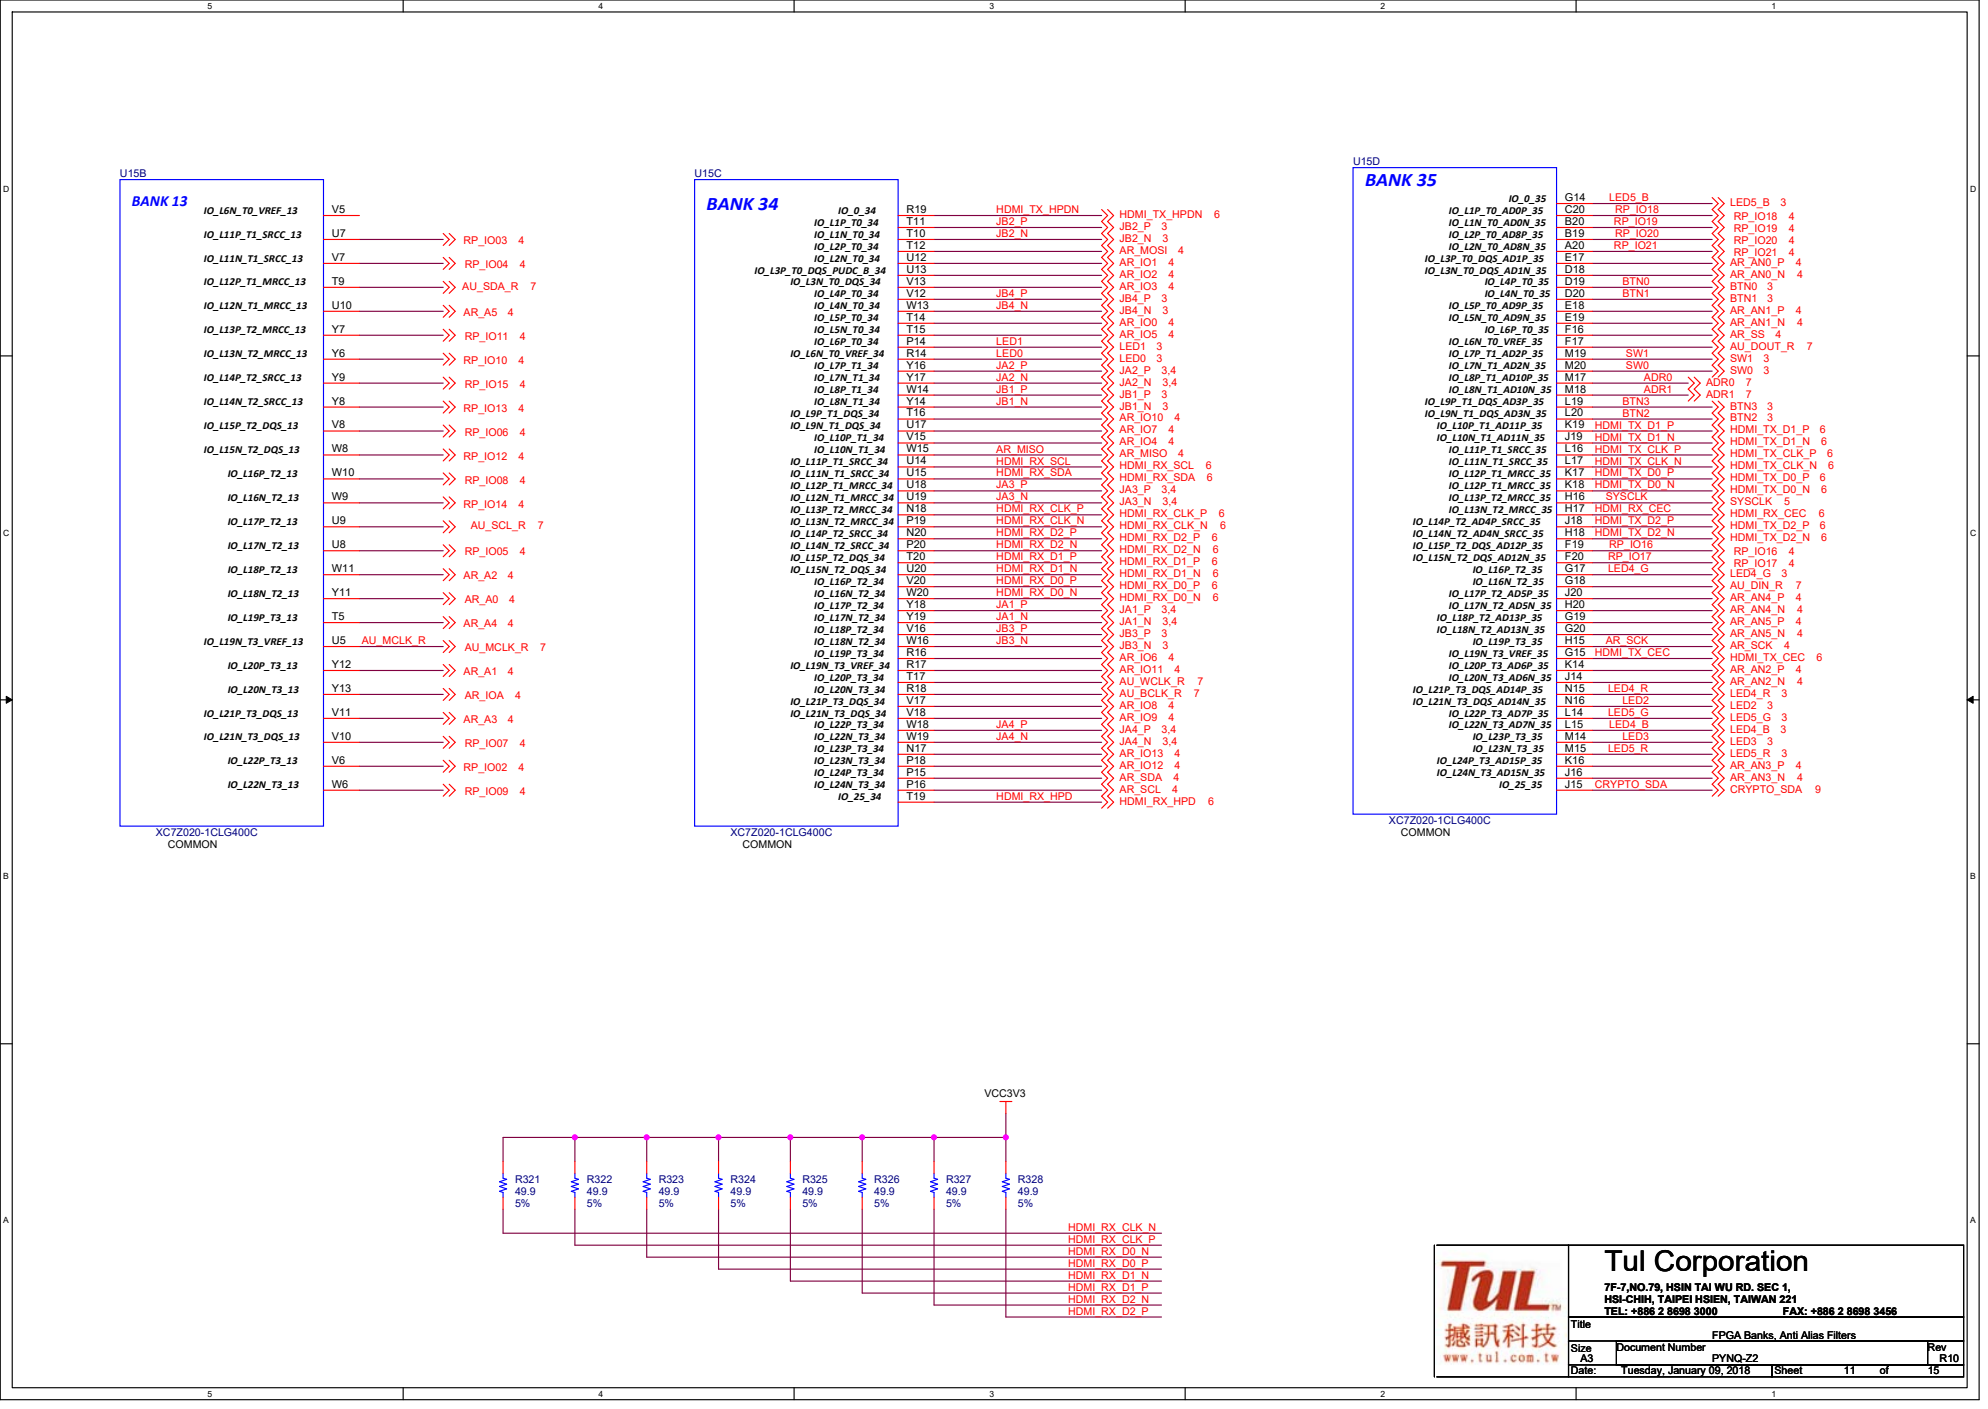
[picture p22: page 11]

7F-7,NO.79, HSIN TAI WU RD. SEC 1,

FPGA Banks, Anti Alias Filters

## POWER

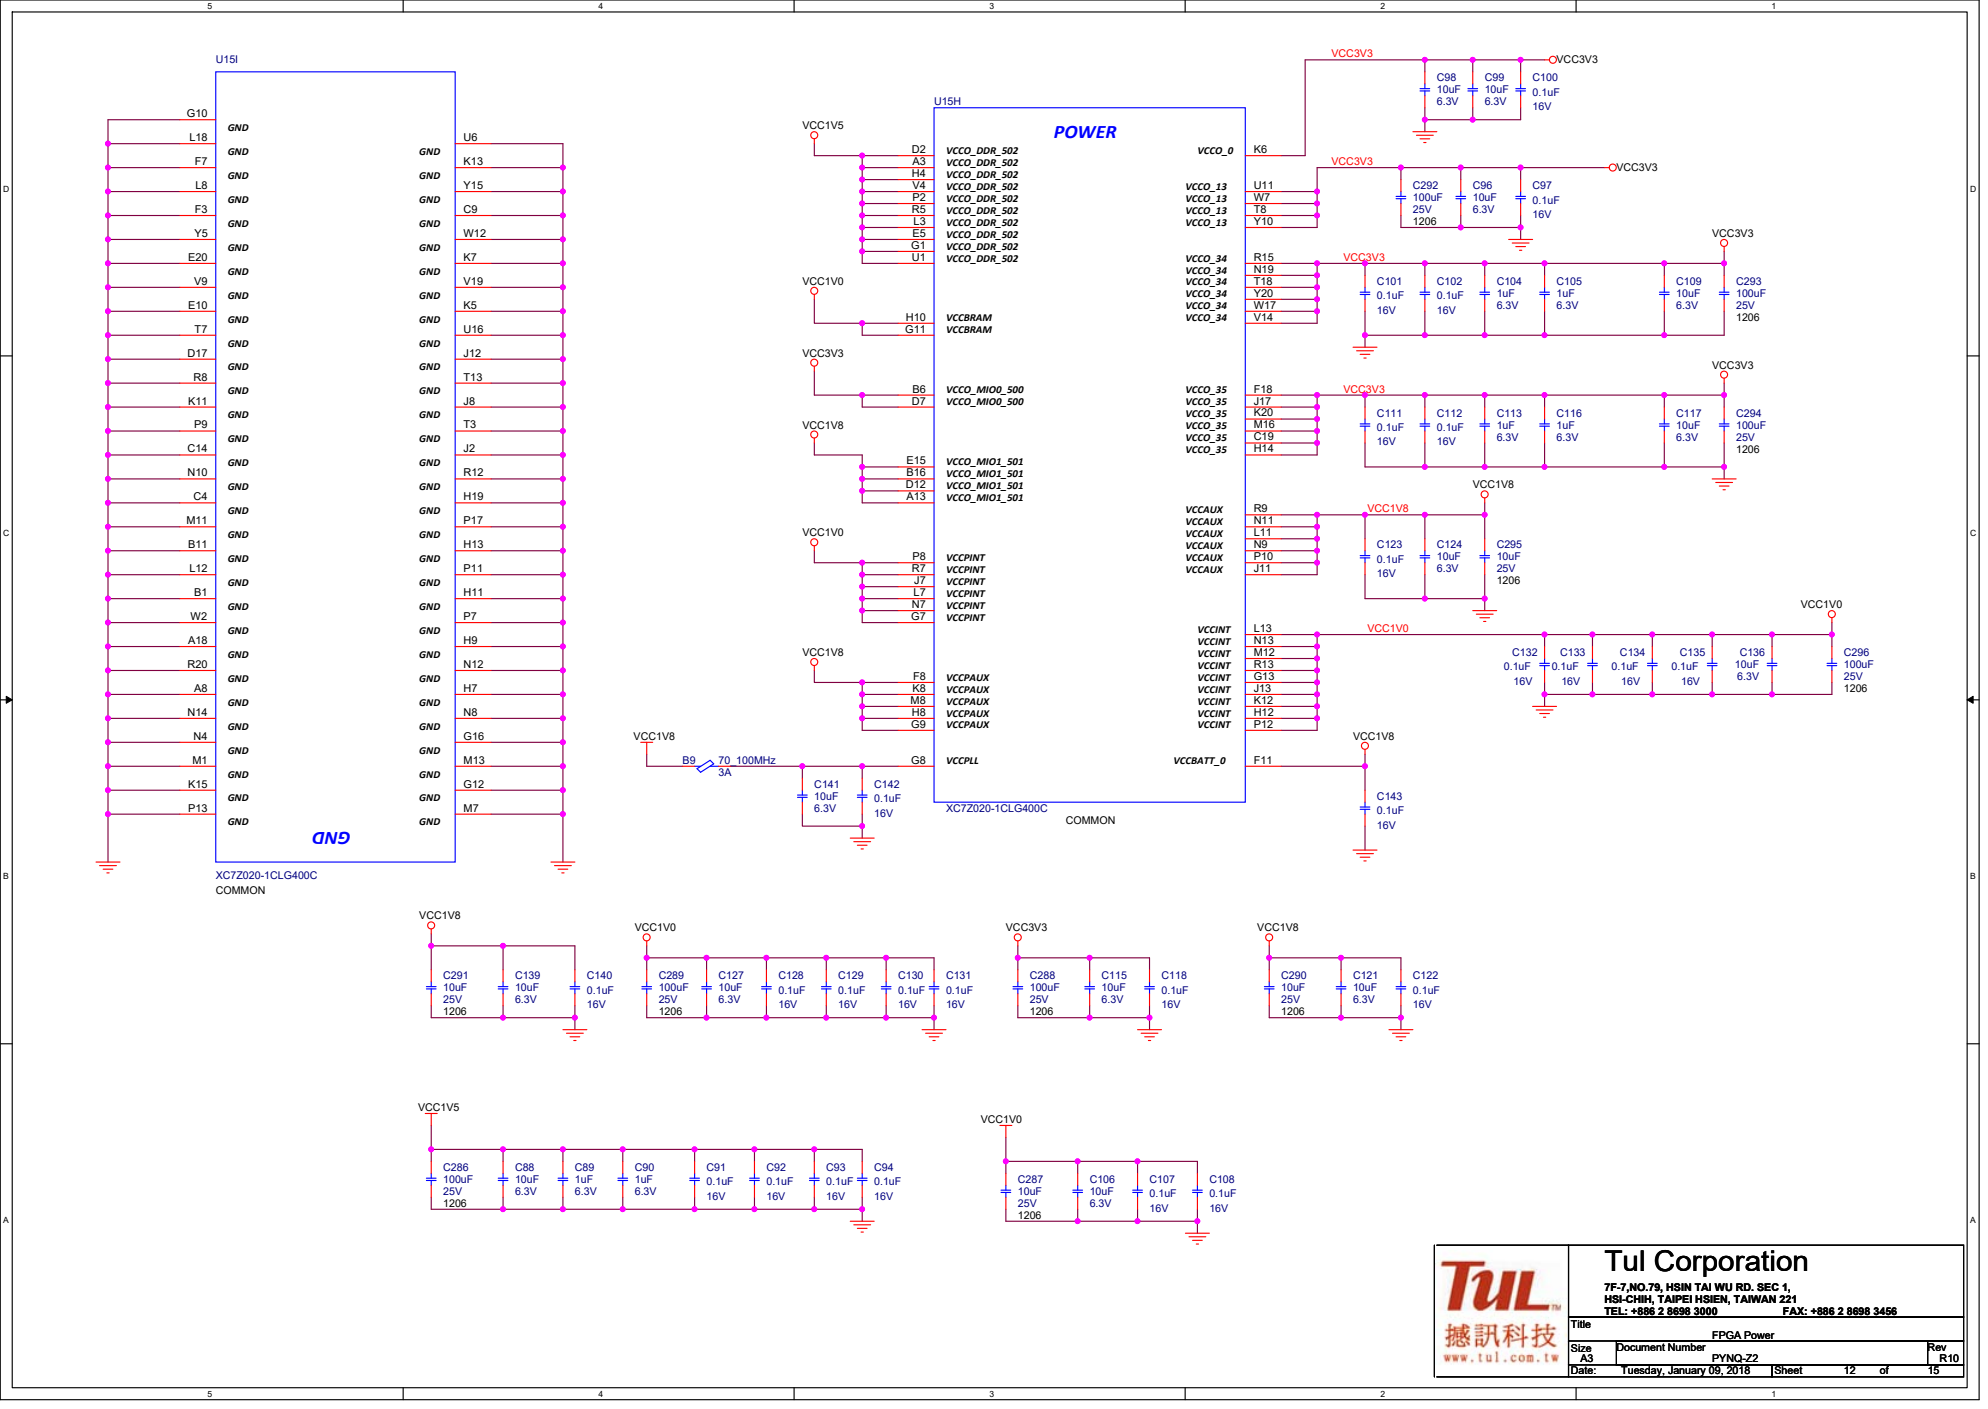
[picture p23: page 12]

7F-7,NO.79, HSIN TAI WU RD. SEC 1,


7F-7,NO.79, HSIN TAI WU RD. SEC 1,

## SW1 : 1.0V 2.6A SW2 : 3.3V 1.6A


Driving CE with a push‐pull output is not recommended.

7F-7,NO.79, HSIN TAI WU RD. SEC 1,


MAIN Power Select 1:2 =>REG 2:3 =>USB

7F-7,NO.79, HSIN TAI WU RD. SEC 1,
HSI-CHIH, TAIPEI HSIEN, TAIWAN 221

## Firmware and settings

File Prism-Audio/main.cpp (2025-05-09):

#include "channel.hpp"
#include "chainFX.hpp"
#include "audioHelper.hpp"
#include "resourceManager.hpp"
#include "libs/modifiers.hpp"

int main() {
    // Audio::Manager amang;
    // amang.parsePAB("AudioBank/audio_bank.pab");
    Audio::Manager audioManager;
    audioManager.initialize("AudioBank/audio_bank.pab");
    audioManager.parsePAB();

    Audio::AudioBuffer buffer(1);
    Audio::Modifiers modifer;
    modifer.processModifier(0, 0, buffer);
    // Audio::Engine mainEngine;
    

    return 0;
}

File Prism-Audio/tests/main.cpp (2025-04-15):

#include "testFramework.hpp"

// Forward declarations of test suites
void register_audio_buffer_tests(TestFramework& framework);
void register_chain_fx_tests(TestFramework& framework);
void register_channel_tests(TestFramework& framework);

int main() {
    TestFramework framework;
    
    // Register all test suites
    register_audio_buffer_tests(framework);
    register_chain_fx_tests(framework);
    register_channel_tests(framework);
    
    // Run all tests
    framework.run_all();
    
    return framework.get_exit_code();
}

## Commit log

2025-02-15 [+] add PCB design files
    [93AA56BT-I_OT.step, CP-32-4_ADI.step, EDI2CAP.CFG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]
2025-02-15 [+] add fpga footprint
    [PJ-037AH.step, Power_management.kicad_sch]
2025-02-15 [+] pushing to save major progress
    [DDR.kicad_sch, EDI2CAP.CFG, MT41K512M16HA-125__A.stp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]
2025-02-19 [+] pre-BOM push
    [DDR.kicad_sch, audio.kicad_sch, fpga-power.kicad_sch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]
2025-02-19 added audio_start
    [DDR.kicad_sch, Power_management.kicad_sch, SOT23_TO-236AB_NEX.stl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]
2025-02-19 Added headphoen audio
    [RTE0016B.stl, fpga-power.kicad_sch, gameboy.kicad_sch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]
2025-02-19 some part done
    [DDR.kicad_sch, DSC1121CE5-050.0000.stp, EDI2CAP.CFG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]
2025-02-25 [+] add ZynqPCB
    [EDI2CAP.CFG, NC7WZ07P6X.stp, PMBT3904,215.stp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]
2025-02-27 [+] add new PCB
    [93AA56BT-I_OT.step, Audio.kicad_sch, Audio.sch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]
2025-02-27 some changes
    [LCD50.kicad_sch, USB.kicad_sch]
2025-03-01 Added Functional RTL for Thread
2025-03-02 added test for thread
2025-03-03 [+] Layouting
    [Audio.kicad_sch, LCD50.kicad_sch, USB.kicad_sch]
2025-03-04 added LCD routing
    [Audio.kicad_sch, DDR3.kicad_sch, LCD50.kicad_sch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]
2025-03-05 [+] routing done, need to fix minor errors.
    [Audio.kicad_sch, DDR3.kicad_sch, LCD50.kicad_sch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]
2025-03-05 need to fix power planes
2025-03-05 Resolved most of the errors
    [LCD50.kicad_sch, USB.kicad_sch, power.kicad_sch]
2025-03-05 [+] complete PCB design
    [Audio.kicad_sch, LCD50.kicad_sch, power.kicad_sch]
2025-03-07 [+] add gerber
    [DFTBoard-BOTTOM.gbr, DFTBoard-B_Mask.gbr, DFTBoard-B_Paste.gbr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]
2025-03-09 Added Rough Core
    [thread_test_time_synth.sdf]
2025-03-10 [+] add XDC files
    [Copy of BoM.xlsx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]
2025-03-25 Added RTL submodule
    [Audio.kicad_sch, Audio.sch, DDR.kicad_sch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]
2025-03-25 Added PCB submodule
2025-06-20 Updated enclosure images
